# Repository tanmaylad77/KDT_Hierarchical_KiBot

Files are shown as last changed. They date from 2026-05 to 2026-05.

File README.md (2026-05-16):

<p align="center" width="100%">
  
</p>

<h1 align="center">LE_BMS_A_V2</h1>

<p align="center" width="100%">
  <a href="https://github.com/nguyen-v/KDT_Hierarchical_KiBot/actions/workflows/ci.yaml">
    
  </a>
</p>

<p align="center" width="100%">
    
</p>

***

<p align="center">
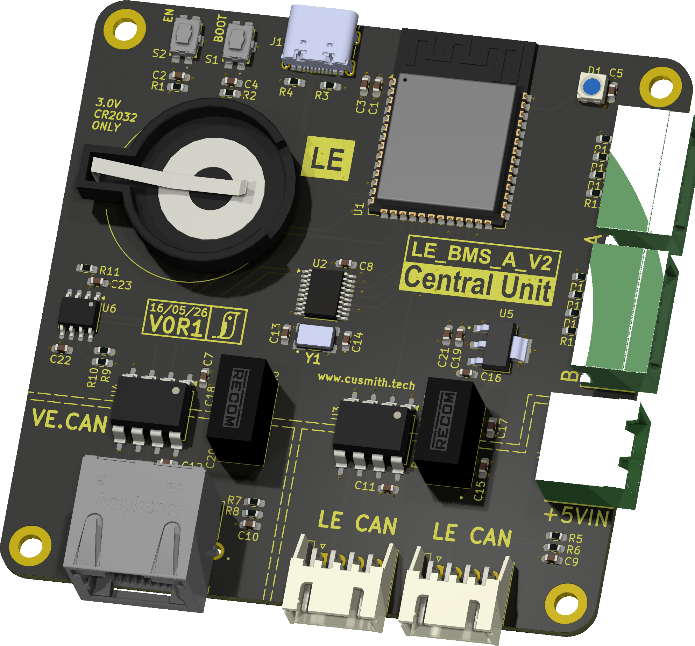
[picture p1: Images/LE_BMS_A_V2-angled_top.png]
3D Top Angled
  
&nbsp; &nbsp; &nbsp; &nbsp;
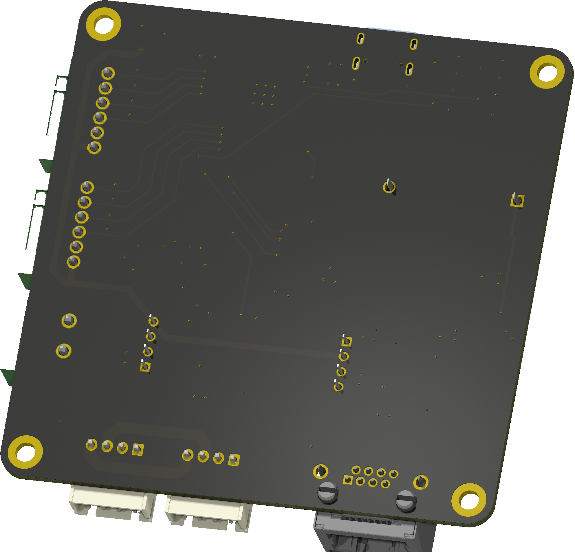
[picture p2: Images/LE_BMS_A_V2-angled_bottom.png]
3D Bottom Angled
  
</p>

***

## SPECIFICATIONS

| Parameter | Value | 
| --- | --- |
| Dimensions | 80.0 × 80.0 mm |

***

## DIRECTORY STRUCTURE

    .
    ├─ Computations       # Misc calculations
    ├─ HTML               # HTML files for generated webpage
    ├─ Images             # Pictures and renders
    │
    ├─ kibot_resources    # External resources for KiBot
    │  ├─ colors          # Color theme for KiCad
    │  ├─ fonts           # Fonts used in the project
    │  ├─ scripts         # External scripts used with KiBot
    │  └─ templates       # Templates for KiBot generated reports
    │
    ├─ kibot_yaml         # KiBot YAML config files
    ├─ KiRI               # KiRI (PCB diff viewer) files
    │
    ├─ lib                # KiCad footprint and symbol libraries
    │  ├─ 3d_models       # Component 3D models
    │  ├─ lib_fp          # Footprint libraries
    │  └─ lib_sym         # Symbol libraries
    │
    ├─ Logos              # Logos
    │
    ├─ Manufacturing      # Assembly and fabrication documents
    │  ├─ Assembly        # Assembly documents (BoM, pos, notes)
    │  │
    │  └─ Fabrication     # Fabrication documents (ZIP, notes)
    │     ├─ Drill Tables # CSV drill tables
    │     └─ Gerbers      # Gerbers
    │
    ├─ Report             # Reports for ERC/DRC
    ├─ Schematic          # PDF of schematic
    ├─ Templates          # Title block templates
    ├─ Testing
    │  └─ Testpoints      # Testpoints tables      
    │
    └─ Variants           # Outputs for assembly variants

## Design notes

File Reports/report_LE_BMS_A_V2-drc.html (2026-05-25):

Logo

(https://github.com/INTI-CMNB/KiBot/) | DRC report for LE_BMS_A_V2
| PCB: LE_BMS_A_V2 Revision: + (Unreleased) Date: 2026-05-25T16:28:53+0000 KiCad Version: 9.0.7 | Errors: 0 Warnings: 95 Total: 95

Violations

Type | Description | Details
silk_edge_clearance | Silkscreen clipped by board edge | @(193.15 mm, 122.61 mm): Segment on Edge.Cuts @(193.15 mm, 95.61 mm): Segment on F.Silkscreen
silk_edge_clearance | Silkscreen clipped by board edge | @(113.15 mm, 50.61 mm): Segment on Edge.Cuts @(179.15 mm, 101.61 mm): Segment on F.Silkscreen
silk_edge_clearance | Silkscreen clipped by board edge | @(193.15 mm, 122.61 mm): Segment on Edge.Cuts @(193.15 mm, 94.61 mm): Segment on F.Silkscreen
silk_edge_clearance | Silkscreen clipped by board edge | @(113.15 mm, 50.61 mm): Segment on Edge.Cuts @(149.15 mm, 102.61 mm): Segment on F.Silkscreen
silk_edge_clearance | Silkscreen clipped by board edge | @(193.15 mm, 122.61 mm): Segment on Edge.Cuts @(183.9 mm, 96.52 mm): Segment of J4 on F.Silkscreen
silk_edge_clearance | Silkscreen clipped by board edge | @(193.15 mm, 122.61 mm): Segment on Edge.Cuts @(196.1 mm, 108.88 mm): Segment of J4 on F.Silkscreen
silk_edge_clearance | Silkscreen clipped by board edge | @(117.15 mm, 126.61 mm): Segment on Edge.Cuts @(168.74 mm, 129.51 mm): Segment of J6 on F.Silkscreen
silk_edge_clearance | Silkscreen clipped by board edge | @(117.15 mm, 126.61 mm): Segment on Edge.Cuts @(171.05 mm, 123.4 mm): Segment of J6 on F.Silkscreen
silk_edge_clearance | Silkscreen clipped by board edge | @(117.15 mm, 126.61 mm): Segment on Edge.Cuts @(171.55 mm, 128.9 mm): Segment of J6 on F.Silkscreen
silk_edge_clearance | Silkscreen clipped by board edge | @(117.15 mm, 126.61 mm): Segment on Edge.Cuts @(173.55 mm, 123.4 mm): Segment of J6 on F.Silkscreen
silk_edge_clearance | Silkscreen clipped by board edge | @(117.15 mm, 126.61 mm): Segment on Edge.Cuts @(174.05 mm, 128.9 mm): Segment of J6 on F.Silkscreen
silk_edge_clearance | Silkscreen clipped by board edge | @(117.15 mm, 126.61 mm): Segment on Edge.Cuts @(176.05 mm, 123.4 mm): Segment of J6 on F.Silkscreen
silk_edge_clearance | Silkscreen clipped by board edge | @(117.15 mm, 126.61 mm): Segment on Edge.Cuts @(176.55 mm, 128.9 mm): Segment of J6 on F.Silkscreen
silk_edge_clearance | Silkscreen clipped by board edge | @(117.15 mm, 126.61 mm): Segment on Edge.Cuts @(178.55 mm, 123.4 mm): Segment of J6 on F.Silkscreen
silk_edge_clearance | Silkscreen clipped by board edge | @(117.15 mm, 126.61 mm): Segment on Edge.Cuts @(179.05 mm, 128.9 mm): Segment of J6 on F.Silkscreen
silk_edge_clearance | Silkscreen clipped by board edge | @(117.15 mm, 126.61 mm): Segment on Edge.Cuts @(181.36 mm, 129.51 mm): Segment of J6 on F.Silkscreen
silk_edge_clearance | Silkscreen clipped by board edge | @(189.15 mm, 46.61 mm): Segment on Edge.Cuts @(139.04 mm, 45.8 mm): Segment of J1 on F.Silkscreen
silk_edge_clearance | Silkscreen clipped by board edge | @(189.15 mm, 46.61 mm): Segment on Edge.Cuts @(147.98 mm, 45.8 mm): Segment of J1 on F.Silkscreen
silk_edge_clearance | Silkscreen clipped by board edge | @(117.15 mm, 126.61 mm): Segment on Edge.Cuts @(125.195 mm, 129.46 mm): Segment of J5 on F.Silkscreen
silk_edge_clearance | Silkscreen clipped by board edge | @(117.15 mm, 126.61 mm): Segment on Edge.Cuts @(141.705 mm, 129.46 mm): Segment of J5 on F.Silkscreen
silk_edge_clearance | Silkscreen clipped by board edge | @(117.15 mm, 126.61 mm): Segment on Edge.Cuts @(153.14 mm, 129.51 mm): Segment of J2 on F.Silkscreen
silk_edge_clearance | Silkscreen clipped by board edge | @(117.15 mm, 126.61 mm): Segment on Edge.Cuts @(155.45 mm, 123.4 mm): Segment of J2 on F.Silkscreen
silk_edge_clearance | Silkscreen clipped by board edge | @(117.15 mm, 126.61 mm): Segment on Edge.Cuts @(155.95 mm, 128.9 mm): Segment of J2 on F.Silkscreen
silk_edge_clearance | Silkscreen clipped by board edge | @(117.15 mm, 126.61 mm): Segment on Edge.Cuts @(157.95 mm, 123.4 mm): Segment of J2 on F.Silkscreen
silk_edge_clearance | Silkscreen clipped by board edge | @(117.15 mm, 126.61 mm): Segment on Edge.Cuts @(158.45 mm, 128.9 mm): Segment of J2 on F.Silkscreen
silk_edge_clearance | Silkscreen clipped by board edge | @(117.15 mm, 126.61 mm): Segment on Edge.Cuts @(160.45 mm, 123.4 mm): Segment of J2 on F.Silkscreen
silk_edge_clearance | Silkscreen clipped by board edge | @(117.15 mm, 126.61 mm): Segment on Edge.Cuts @(160.95 mm, 128.9 mm): Segment of J2 on F.Silkscreen
silk_edge_clearance | Silkscreen clipped by board edge | @(117.15 mm, 126.61 mm): Segment on Edge.Cuts @(162.95 mm, 123.4 mm): Segment of J2 on F.Silkscreen
silk_edge_clearance | Silkscreen clipped by board edge | @(117.15 mm, 126.61 mm): Segment on Edge.Cuts @(163.45 mm, 128.9 mm): Segment of J2 on F.Silkscreen
silk_edge_clearance | Silkscreen clipped by board edge | @(117.15 mm, 126.61 mm): Segment on Edge.Cuts @(165.76 mm, 129.51 mm): Segment of J2 on F.Silkscreen
silk_edge_clearance | Silkscreen clipped by board edge | @(193.15 mm, 122.61 mm): Segment on Edge.Cuts @(185.8 mm, 56.3 mm): Segment of J3 on F.Silkscreen
silk_edge_clearance | Silkscreen clipped by board edge | @(193.15 mm, 122.61 mm): Segment on Edge.Cuts @(196.1 mm, 73.5 mm): Segment of J3 on F.Silkscreen
silk_edge_clearance | Silkscreen clipped by board edge | @(193.15 mm, 122.61 mm): Segment on Edge.Cuts @(185.8 mm, 75.5 mm): Segment of J7 on F.Silkscreen
silk_edge_clearance | Silkscreen clipped by board edge | @(193.15 mm, 122.61 mm): Segment on Edge.Cuts @(196.1 mm, 92.7 mm): Segment of J7 on F.Silkscreen
lib_footprint_mismatch | Footprint 'C_0603_1608Metric_Pad1.08x0.95mm_HandSolder' does not match copy in library 'Capacitor_SMD'. | @(132.575 mm, 56.35 mm): Footprint C4
lib_footprint_mismatch | Footprint 'SOP-8_6.62x9.15mm_P2.54mm' does not match copy in library 'Package_SO'. | @(160.0675 mm, 102.585 mm): Footprint U3
lib_footprint_mismatch | Footprint 'C_0603_1608Metric_Pad1.08x0.95mm_HandSolder' does not match copy in library 'Capacitor_SMD'. | @(150.176802 mm, 54.8 mm): Footprint C3
lib_footprint_mismatch | Footprint 'C_0603_1608Metric_Pad1.08x0.95mm_HandSolder' does not match copy in library 'Capacitor_SMD'. | @(138.75 mm, 99.51 mm): Footprint C18
lib_footprint_mismatch | Footprint 'C_0603_1608Metric_Pad1.08x0.95mm_HandSolder' does not match copy in library 'Capacitor_SMD'. | @(119.7175 mm, 85.625 mm): Footprint C23
lib_footprint_mismatch | Footprint 'R_0603_1608Metric_Pad0.98x0.95mm_HandSolder' does not match copy in library 'Resistor_SMD'. | @(125.525 mm, 57.825 mm): Footprint R1
lib_footprint_mismatch | Footprint 'C_0603_1608Metric_Pad1.08x0.95mm_HandSolder' does not match copy in library 'Capacitor_SMD'. | @(152.0 mm, 79.475 mm): Footprint C8
lib_footprint_mismatch | Footprint 'C_0603_1608Metric_Pad1.08x0.95mm_HandSolder' does not match copy in library 'Capacitor_SMD'. | @(133.25 mm, 109.41 mm): Footprint C12
lib_footprint_mismatch | Footprint 'SOIC-8_3.9x4.9mm_P1.27mm' does not match copy in library 'Package_SO'. | @(118.15 mm, 90.4 mm): Footprint U6
lib_footprint_mismatch | Footprint 'C_0603_1608Metric_Pad1.08x0.95mm_HandSolder' does not match copy in library 'Capacitor_SMD'. | @(153.95 mm, 89.975 mm): Footprint C14
lib_footprint_mismatch | Footprint 'C_0603_1608Metric_Pad1.08x0.95mm_HandSolder' does not match copy in library 'Capacitor_SMD'. | @(166.05 mm, 97.21 mm): Footprint C6
lib_footprint_mismatch | Footprint 'R_0603_1608Metric_Pad0.98x0.95mm_HandSolder' does not match copy in library 'Resistor_SMD'. | @(140.835 mm, 55.383198 mm): Footprint R4
lib_footprint_mismatch | Footprint 'R_0603_1608Metric_Pad0.98x0.95mm_HandSolder' does not match copy in library 'Resistor_SMD'. | @(145.65 mm, 115.01 mm): Footprint R8
lib_footprint_mismatch | Footprint 'C_0603_1608Metric_Pad1.08x0.95mm_HandSolder' does not match copy in library 'Capacitor_SMD'. | @(182.95 mm, 52.0625 mm): Footprint C5
lib_footprint_mismatch | Footprint 'R_0603_1608Metric_Pad0.98x0.95mm_HandSolder' does not match copy in library 'Resistor_SMD'. | @(145.635 mm, 55.383198 mm): Footprint R3
lib_footprint_mismatch | Footprint 'R_0603_1608Metric_Pad0.98x0.95mm_HandSolder' does not match copy in library 'Resistor_SMD'. | @(186.25 mm, 113.61 mm): Footprint R5
lib_footprint_mismatch | Footprint 'R_0603_1608Metric_Pad0.98x0.95mm_HandSolder' does not match copy in library 'Resistor_SMD'. | @(183.4375 mm, 80.35 mm): Footprint R18
lib_footprint_mismatch | Footprint 'JST_XH_S4B-XH-A_1x04_P2.50mm_Horizontal' does not match copy in library 'Connector_JST'. | @(171.3 mm, 120.2 mm): Footprint J6
lib_footprint_mismatch | Footprint 'R_0603_1608Metric_Pad0.98x0.95mm_HandSolder' does not match copy in library 'Resistor_SMD'. | @(117.945 mm, 83.925 mm): Footprint R11
lib_footprint_mismatch | Footprint 'R_0603_1608Metric_Pad0.98x0.95mm_HandSolder' does not match copy in library 'Resistor_SMD'. | @(183.2875 mm, 61.16 mm): Footprint R14
lib_footprint_mismatch | Footprint 'C_0603_1608Metric_Pad1.08x0.95mm_HandSolder' does not match copy in library 'Capacitor_SMD'. | @(145.75 mm, 89.975 mm): Footprint C13
lib_footprint_mismatch | Footprint 'C_0603_1608Metric_Pad1.08x0.95mm_HandSolder' does not match copy in library 'Capacitor_SMD'. | @(168.775 mm, 87.7 mm): Footprint C19
lib_footprint_mismatch | Footprint 'C_0603_1608Metric_Pad1.08x0.95mm_HandSolder' does not match copy in library 'Capacitor_SMD'. | @(175.0375 mm, 105.31 mm): Footprint C15
lib_footprint_mismatch | Footprint 'R_0603_1608Metric_Pad0.98x0.95mm_HandSolder' does not match copy in library 'Resistor_SMD'. | @(183.2875 mm, 66.18 mm): Footprint R12
lib_footprint_mismatch | Footprint 'ESP32-S3-WROOM-2' does not match copy in library 'RF_Module'. | @(162.86 mm, 59.36 mm): Footprint U1
lib_footprint_mismatch | Footprint 'R_0603_1608Metric_Pad0.98x0.95mm_HandSolder' does not match copy in library 'Resistor_SMD'. | @(145.65 mm, 113.41 mm): Footprint R7
lib_footprint_mismatch | Footprint 'SOP-8_6.62x9.15mm_P2.54mm' does not match copy in library 'Package_SO'. | @(130.3 mm, 102.51 mm): Footprint U4
lib_footprint_mismatch | Footprint 'C_0603_1608Metric_Pad1.08x0.95mm_HandSolder' does not match copy in library 'Capacitor_SMD'. | @(175.1 mm, 99.65 mm): Footprint C17
lib_footprint_mismatch | Footprint 'R_0603_1608Metric_Pad0.98x0.95mm_HandSolder' does not match copy in library 'Resistor_SMD'. | @(122.255 mm, 96.525 mm): Footprint R10
lib_footprint_mismatch | Footprint 'R_0603_1608Metric_Pad0.98x0.95mm_HandSolder' does not match copy in library 'Resistor_SMD'. | @(183.2875 mm, 63.67 mm): Footprint R13
lib_footprint_mismatch | Footprint 'R_0603_1608Metric_Pad0.98x0.95mm_HandSolder' does not match copy in library 'Resistor_SMD'. | @(186.25 mm, 115.21 mm): Footprint R6
lib_footprint_mismatch | Footprint 'R_0603_1608Metric_Pad0.98x0.95mm_HandSolder' does not match copy in library 'Resistor_SMD'. | @(132.575 mm, 57.85 mm): Footprint R2
lib_footprint_mismatch | Footprint 'R_0603_1608Metric_Pad0.98x0.95mm_HandSolder' does not match copy in library 'Resistor_SMD'. | @(183.2875 mm, 58.65 mm): Footprint R15
lib_footprint_mismatch | Footprint 'C_0603_1608Metric_Pad1.08x0.95mm_HandSolder' does not match copy in library 'Capacitor_SMD'. | @(162.95 mm, 109.61 mm): Footprint C11
lib_footprint_mismatch | Footprint 'R_0603_1608Metric_Pad0.98x0.95mm_HandSolder' does not match copy in library 'Resistor_SMD'. | @(183.4375 mm, 82.86 mm): Footprint R17
lib_footprint_mismatch | Footprint 'C_0603_1608Metric_Pad1.08x0.95mm_HandSolder' does not match copy in library 'Capacitor_SMD'. | @(145.65 mm, 116.61 mm): Footprint C10
lib_footprint_mismatch | Footprint 'JST_XH_S4B-XH-A_1x04_P2.50mm_Horizontal' does not match copy in library 'Connector_JST'. | @(155.7 mm, 120.2 mm): Footprint J2
lib_footprint_mismatch | Footprint 'C_0603_1608Metric_Pad1.08x0.95mm_HandSolder' does not match copy in library 'Capacitor_SMD'. | @(116.645 mm, 95.325 mm): Footprint C22
lib_footprint_mismatch | Footprint 'C_0603_1608Metric_Pad1.08x0.95mm_HandSolder' does not match copy in library 'Capacitor_SMD'. | @(186.25 mm, 116.81 mm): Footprint C9
lib_footprint_mismatch | Footprint 'C_0603_1608Metric_Pad1.08x0.95mm_HandSolder' does not match copy in library 'Capacitor_SMD'. | @(151.876802 mm, 54.8 mm): Footprint C1
lib_footprint_mismatch | Footprint 'R_0603_1608Metric_Pad0.98x0.95mm_HandSolder' does not match copy in library 'Resistor_SMD'. | @(183.4375 mm, 77.84 mm): Footprint R19
lib_footprint_mismatch | Footprint 'C_0603_1608Metric_Pad1.08x0.95mm_HandSolder' does not match copy in library 'Capacitor_SMD'. | @(138.85 mm, 104.61 mm): Footprint C20
lib_footprint_mismatch | Footprint 'TSSOP-20_4.4x6.5mm_P0.65mm' does not match copy in library 'Package_SO'. | @(149.9875 mm, 84.0 mm): Footprint U2
lib_footprint_mismatch | Footprint 'C_0603_1608Metric_Pad1.08x0.95mm_HandSolder' does not match copy in library 'Capacitor_SMD'. | @(136.05 mm, 97.11 mm): Footprint C7
lib_footprint_mismatch | Footprint 'C_0603_1608Metric_Pad1.08x0.95mm_HandSolder' does not match copy in library 'Capacitor_SMD'. | @(170.575 mm, 92.7 mm): Footprint C16
lib_footprint_mismatch | Footprint 'C_0603_1608Metric_Pad1.08x0.95mm_HandSolder' does not match copy in library 'Capacitor_SMD'. | @(167.075 mm, 87.7 mm): Footprint C21
lib_footprint_mismatch | Footprint 'R_0603_1608Metric_Pad0.98x0.95mm_HandSolder' does not match copy in library 'Resistor_SMD'. | @(183.4375 mm, 85.37 mm): Footprint R16
lib_footprint_mismatch | Footprint 'R_0603_1608Metric_Pad0.98x0.95mm_HandSolder' does not match copy in library 'Resistor_SMD'. | @(122.255 mm, 94.925 mm): Footprint R9
lib_footprint_mismatch | Footprint 'C_0603_1608Metric_Pad1.08x0.95mm_HandSolder' does not match copy in library 'Capacitor_SMD'. | @(125.525 mm, 56.325 mm): Footprint C2
silk_over_copper | Silkscreen clipped by solder mask | @(179.15 mm, 101.61 mm): Segment on F.Silkscreen
solder_mask_bridge | Front solder mask aperture bridges items with different nets | @(146.71 mm, 53.145 mm): Pad A1_B12 [GND] of J1 on L1 (Sig, PWR) @(145.91 mm, 53.145 mm): Pad A4_B9 [unconnected-(J1-VBUS-PadA4_B9)] of J1 on L1 (Sig, PWR)
solder_mask_bridge | Front solder mask aperture bridges items with different nets | @(145.91 mm, 53.145 mm): Pad A4_B9 [unconnected-(J1-VBUS-PadA4_B9)] of J1 on L1 (Sig, PWR) @(145.26 mm, 53.145 mm): Pad B8 [unconnected-(J1-SBU2-PadB8)] of J1 on L1 (Sig, PWR)
solder_mask_bridge | Front solder mask aperture bridges items with different nets | @(144.76 mm, 53.145 mm): Pad A5 [/Project Architecture/Section A - Title A/USB_CC1] of J1 on L1 (Sig, PWR) @(145.26 mm, 53.145 mm): Pad B8 [unconnected-(J1-SBU2-PadB8)] of J1 on L1 (Sig, PWR)
solder_mask_bridge | Front solder mask aperture bridges items with different nets | @(144.76 mm, 53.145 mm): Pad A5 [/Project Architecture/Section A - Title A/USB_CC1] of J1 on L1 (Sig, PWR) @(144.26 mm, 53.145 mm): Pad B7 [/Project Architecture/Section A - Title A/ESP32_USB_D-] of J1 on L1 (Sig, PWR)
solder_mask_bridge | Front solder mask aperture bridges items with different nets | @(143.76 mm, 53.145 mm): Pad A6 [/Project Architecture/Section A - Title A/ESP32_USB_D+] of J1 on L1 (Sig, PWR) @(143.26 mm, 53.145 mm): Pad A7 [/Project Architecture/Section A - Title A/ESP32_USB_D-] of J1 on L1 (Sig, PWR)
solder_mask_bridge | Front solder mask aperture bridges items with different nets | @(143.76 mm, 53.145 mm): Pad A6 [/Project Architecture/Section A - Title A/ESP32_USB_D+] of J1 on L1 (Sig, PWR) @(144.26 mm, 53.145 mm): Pad B7 [/Project Architecture/Section A - Title A/ESP32_USB_D-] of J1 on L1 (Sig, PWR)
solder_mask_bridge | Front solder mask aperture bridges items with different nets | @(143.26 mm, 53.145 mm): Pad A7 [/Project Architecture/Section A - Title A/ESP32_USB_D-] of J1 on L1 (Sig, PWR) @(142.76 mm, 53.145 mm): Pad B6 [/Project Architecture/Section A - Title A/ESP32_USB_D+] of J1 on L1 (Sig, PWR)
solder_mask_bridge | Front solder mask aperture bridges items with different nets | @(142.26 mm, 53.145 mm): Pad A8 [unconnected-(J1-SBU1-PadA8)] of J1 on L1 (Sig, PWR) @(141.76 mm, 53.145 mm): Pad B5 [/Project Architecture/Section A - Title A/USB_CC2] of J1 on L1 (Sig, PWR)
solder_mask_bridge | Front solder mask aperture bridges items with different nets | @(142.26 mm, 53.145 mm): Pad A8 [unconnected-(J1-SBU1-PadA8)] of J1 on L1 (Sig, PWR) @(142.76 mm, 53.145 mm): Pad B6 [/Project Architecture/Section A - Title A/ESP32_USB_D+] of J1 on L1 (Sig, PWR)
solder_mask_bridge | Front solder mask aperture bridges items with different nets | @(140.31 mm, 53.145 mm): Pad B1_A12 [GND] of J1 on L1 (Sig, PWR) @(141.11 mm, 53.145 mm): Pad B4_A9 [unconnected-(J1-VBUS-PadA4_B9)_1] of J1 on L1 (Sig, PWR)
solder_mask_bridge | Front solder mask aperture bridges items with different nets | @(141.11 mm, 53.145 mm): Pad B4_A9 [unconnected-(J1-VBUS-PadA4_B9)_1] of J1 on L1 (Sig, PWR) @(141.76 mm, 53.145 mm): Pad B5 [/Project Architecture/Section A - Title A/USB_CC2] of J1 on L1 (Sig, PWR)

Generated by KiBot (https://github.com/INTI-CMNB/KiBot/) v1.9.1

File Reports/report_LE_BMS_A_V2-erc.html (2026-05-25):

Logo

(https://github.com/INTI-CMNB/KiBot/) | ERC report for LE_BMS_A_V2
| Schematic: LE_BMS_A_V2 Revision: + (Unreleased) Date: 2026-05-25T16:28:51+0000 KiCad Version: 9.0.7 | Errors: 0 Warnings: 6 Total: 6

Sheet / (LE_BMS_A_V2.kicad_sch)

Type | Description | Details
lib_symbol_mismatch | Symbol 'RFM-0505S' doesn't match copy in library 'RFM-0505S' | @(1.1176 mm, 0.6477 mm): Symbol PS1 [RFM-0505S]
lib_symbol_mismatch | Symbol '691313510002' doesn't match copy in library '691313510002' | @(0.9906 mm, 1.1938 mm): Symbol J4 [691313510002]
lib_symbol_mismatch | Symbol 'RFM-0505S' doesn't match copy in library 'RFM-0505S' | @(1.6764 mm, 0.6477 mm): Symbol PS2 [RFM-0505S]
lib_symbol_mismatch | Symbol 'TLV1117LV33DCYT' doesn't match copy in library 'TLV1117LV33DCYT' | @(1.4351 mm, 1.1684 mm): Symbol U5 [TLV1117LV33DCYT]
lib_symbol_mismatch | Symbol 'Battery_Cell' doesn't match copy in library 'Device' | @(1.7399 mm, 0.6096 mm): Symbol BT1 [Battery_Cell]

Sheet /Project Architecture/Section C - POWER/ (untitled.kicad_sch)

Type | Description | Details
pin_to_pin | Pins of type Bidirectional and Power output are connected | @(1.6129 mm, 1.143 mm): Symbol U5 Pin 4 [OUT-1, Bidirectional, Line] @(1.6129 mm, 1.1176 mm): Symbol U5 Pin 2 [OUT, Power output, Line]

Generated by KiBot (https://github.com/INTI-CMNB/KiBot/) v1.9.1

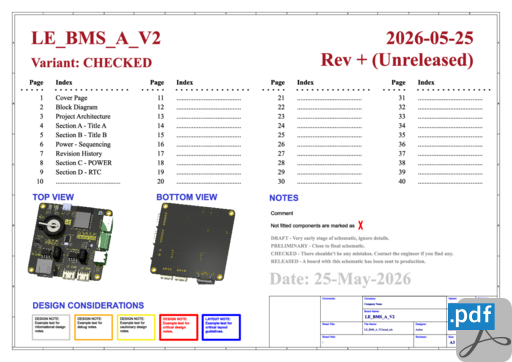
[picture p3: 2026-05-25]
HTML/images/cat_pdf_schematic_LE_BMS_A_V2-schematic.png

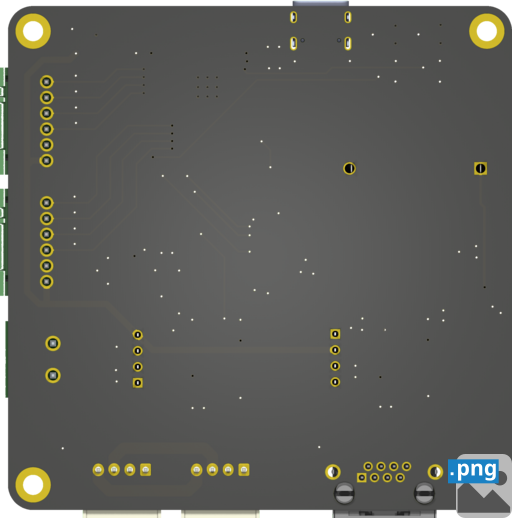
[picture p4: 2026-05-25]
HTML/images/cat_png_3d_viewer_bottom_LE_BMS_A_V2-bottom.png

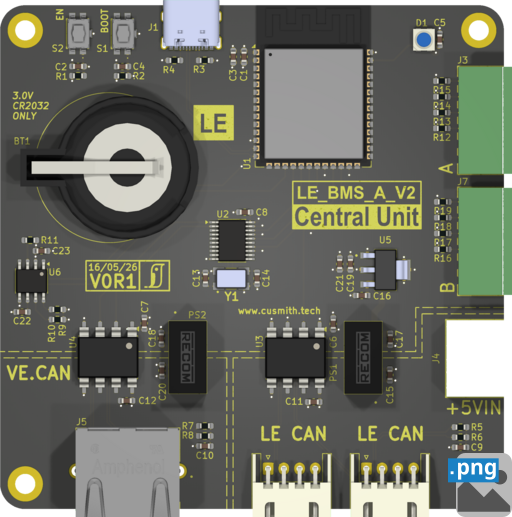
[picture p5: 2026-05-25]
HTML/images/cat_png_3d_viewer_top_LE_BMS_A_V2-top.png

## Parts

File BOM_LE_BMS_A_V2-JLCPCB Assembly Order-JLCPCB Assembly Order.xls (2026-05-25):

JLCPCB BOM Tool - BOM Matching
BOM name：BOM_LE_BMS_A_V2-JLCPCB Assembly Order-JLCPCB Assembly Order.xlsx |  |  | Download Time：2026-05-26 00:19:31 |  |  |  | * Our matching results are updated in real-time, but stock and prices may change. If it's been over 24 hours, please re-match before placing your order.
PCB Assembled Qty：5 |  |  | Est. Total Price：30.7024
Your BOM |  |  |  |  | Matched Parts |  |  |  |  |  |  | Order Information
Top Designator | Bottom Designator | Comment | Footprint | JLCPCB Part # | Matches | Part # | Manufacturer | Footprint | Description | Category | Warning | JLCPCB Part # | Product link | Lib Type | Qty | Source | Total Price ($)
BT1 |  | CR2032 | - |  | Select by System | BS-07-A1BJ001 | MYOUNG | - | -25~85℃ Battery base CR2032 Manganese steel Nickel plated - ROHS | Button And Strip Battery Connector |  | C2979167 | https://jlcpcb.com/partdetail/MYOUNG-BS_07A1BJ001/C2979167 | Extended | 2 | 2 JLCPCB | 0.5516
C1,C3,C5,C6,C7,C8,C11,C12,C15,C16,C17,C18,C19,C20,C21,C22,C23 |  | 1uF | 0603 |  | Select by System | CL10A105KB8NNNC | Samsung Electro-Mechanics | 0603 | 1uF 50V X5R ±10% 0603 Multilayer Ceramic Capacitors MLCC - SMD/SMT ROHS | Multilayer Ceramic Capacitors MLCC - SMD/SMT |  | C15849 | https://jlcpcb.com/partdetail/16531-CL10A105KB8NNNC/C15849 | Basic | 34 | 34 JLCPCB | 0.2584
C2,C4 |  | 0.1uF | 0603 |  | Select by System | CC0603KRX7R9BB104 | YAGEO | 0603 | 100nF 50V X7R ±10% 0603 Multilayer Ceramic Capacitors MLCC - SMD/SMT ROHS | Multilayer Ceramic Capacitors MLCC - SMD/SMT |  | C14663 | https://jlcpcb.com/partdetail/YAGEO-CC0603KRX7R9BB104/C14663 | Basic | 4 | 4 JLCPCB | 0.0128
C9,C10 |  | 4.7n | 0603 |  | Select by System | 0603B472K500NT | FH (Guangdong Fenghua Advanced Tech) | 0603 | 4.7nF 50V X7R ±10% 0603 Multilayer Ceramic Capacitors MLCC - SMD/SMT ROHS | Multilayer Ceramic Capacitors MLCC - SMD/SMT |  | C53987 | https://jlcpcb.com/partdetail/55004-0603B472K500NT/C53987 | Basic | 4 | 4 JLCPCB | 0.014
C13,C14 |  | 10p | 0603 |  | Select by System | CL10C100JB8NNNC | Samsung Electro-Mechanics | 0603 | 10pF 50V C0G ±5% 0603 Multilayer Ceramic Capacitors MLCC - SMD/SMT ROHS | Multilayer Ceramic Capacitors MLCC - SMD/SMT |  | C1634 | https://jlcpcb.com/partdetail/1986-CL10C100JB8NNNC/C1634 | Basic | 4 | 4 JLCPCB | 0.0204
J1 |  | 10155435-00011LF | 插件 |  | Select by System | 10155435-00011LF | Amphenol ICC | 插件 | -25℃~+85℃ 1 3A、5A 5V Female Surface Mount, Right Angle Type-C 插件 USB Connectors ROHS | Global Sourcing Parts |  | C5409177 | https://jlcpcb.com/partdetail/AmphenolICC-1015543500011LF/C5409177 | Extended | 2 | 2 JLCPCB | 1.6232
J2,J6 |  | CAN1 | 弯插,P=2.5mm |  | Select by Customer | S4B-XH-A(LF)(SN) | JST | 弯插,P=2.5mm | -25℃~+85℃ 1 11.5mm 12.4mm 1x4P 2.5mm 250V 3A 4 4P 6.1mm Brass K Pin PA66 Right Angle Tin UL94V-0 White XH 弯插,P=2.5mm Wire To Board Connector ROHS | Wire To Board Connector |  | C157925 | https://jlcpcb.com/partdetail/JST-S4B_XH_A_LF_SN/C157925 | Extended | 5 | 5 JLCPCB | 0.8055
J4 |  | 691313510002 | 插件,P=5.08mm |  | Select by System | 691313510002 | Wurth Elektronik | 插件,P=5.08mm | -40℃~+105℃ 1 1x2P 2 20A 2P 300V 5.08mm Board Side/Socket - Closed Green 插件,P=5.08mm Pluggable System Terminal Block ROHS | Global Sourcing Parts |  | C5362635 | https://jlcpcb.com/partdetail/WurthElektronik-691313510002/C5362635 | Extended | 3 | 3 JLCPCB | 1.6827
J5 |  | RJHSE5380 | 弯插 |  | Select by System | RJHSE5380 | Amphenol ICC | 弯插 | -55℃~+85℃ 1 Gold Non-LED Phosphor bronze RJ45 Jack Right Angle Shielded 弯插 Ethernet Connectors / Modular Connectors (RJ45 RJ11) ROHS | Ethernet Connectors / Modular Connectors (RJ45 RJ11) |  | C464586 | https://jlcpcb.com/partdetail/AmphenolICC-RJHSE5380/C464586 | Extended | 2 | 2 JLCPCB | 1.9928
PS1,PS2 |  | RFM-0505S | SIP,11.5x6mm |  | Select by System | RFM-0505S | YLPTEC | SIP,11.5x6mm | -40℃~+85℃ 1 1.5kV 100kHz 10mm 11.5mm 1W 200mA 2400uF 30mVp-p 5V 5V 6mm 88% Short Circuit Protection、Over-temperature protection、Automatic fault recovery SIP,11.5x6mm Isolated Power Modules ROHS | Isolated Power Modules |  | C22371855 | https://jlcpcb.com/partdetail/YLPTEC-RFM0505S/C22371855 | Extended | 4 | 4 JLCPCB | 7.0772
R1,R2 |  | 100k | 0603 |  | Select by System | 0603WAF1003T5E | UNI-ROYAL(Uniroyal Elec) | 0603 | -55℃~+155℃ 100kΩ 100mW 75V Thick Film Resistor ±1% ±100ppm/℃ 0603 Chip Resistor - Surface Mount ROHS | Chip Resistor - Surface Mount |  | C25803 | https://jlcpcb.com/partdetail/26546-0603WAF1003T5E/C25803 | Basic | 4 | 4 JLCPCB | 0.0072
R3,R4,R9,R10,R11 |  | 5.1k | 0603 |  | Select by System | 0603WAF5101T5E | UNI-ROYAL(Uniroyal Elec) | 0603 | -55℃~+155℃ 100mW 5.1kΩ 75V Thick Film Resistor ±1% ±100ppm/℃ 0603 Chip Resistor - Surface Mount ROHS | Chip Resistor - Surface Mount |  | C23186 | https://jlcpcb.com/partdetail/23913-0603WAF5101T5E/C23186 | Basic | 10 | 10 JLCPCB | 0.016
R5,R6,R7,R8 |  | 50R | 0603 |  | Select by System | RT0603BRE0750RL | YAGEO | 0603 | -55℃~+155℃ 100mW 50Ω 75V Thin Film Resistor ±0.1% ±50ppm/℃ 0603 Chip Resistor - Surface Mount ROHS | Chip Resistor - Surface Mount |  | C849792 | https://jlcpcb.com/partdetail/YAGEO-RT0603BRE0750RL/C849792 | Extended | 20 | 20 JLCPCB | 0.522
R12,R13,R14,R15,R16,R17,R18,R19 |  | 10k | 0603 |  | Select by System | 0603WAF1002T5E | UNI-ROYAL(Uniroyal Elec) | 0603 | -55℃~+155℃ 100mW 10kΩ 75V Thick Film Resistor ±1% ±100ppm/℃ 0603 Chip Resistor - Surface Mount ROHS | Chip Resistor - Surface Mount |  | C25804 | https://jlcpcb.com/partdetail/26547-0603WAF1002T5E/C25804 | Basic | 16 | 16 JLCPCB | 0.0208
S1,S2 |  | EVQ-P2P02W | SMD,4.7x3.5mm |  | Select by System | EVQP2P02W | PANASONIC | SMD,4.7x3.5mm | -40℃~+85℃ 1,000,000 cycles 15V 1N 2.5mm 20mA 3.5mm 4.7mm J-Lead Rectangular Button SPST Surface Mount,Vertical SMD,4.7x3.5mm Tactile Switches ROHS | Tactile Switches |  | C512395 | https://jlcpcb.com/partdetail/PANASONIC-EVQP2P02W/C512395 | Extended | 5 | 5 JLCPCB | 2.025
U2 |  | MCP2515-xST | TSSOP-20 |  | Select by System | MCP2515T-I/ST | Microchip Tech | TSSOP-20 | -40℃~+85℃ 1Mbps 1uA 2.7V~5.5V 5mA CAN Controller SPI TSSOP-20 CAN Controllers ROHS | CAN Controllers |  | C185941 | https://jlcpcb.com/partdetail/MicrochipTech-MCP2515T_IST/C185941 | Extended | 2 | 2 JLCPCB | 2.4106
U3,U4 |  | ISO1050DUB | SOP-8 |  | Select by System | ISO1050DUBR | Texas Instruments | SOP-8 | -55℃~+105℃ 1 1Mbps 2500 3V~5.5V 4.75V~5.25V 50kV/us Bus Fault Detection and Protection、Fail-safe SOP-8 Isolated CAN Transceivers ROHS | Isolated CAN Transceivers |  | C16428 | https://jlcpcb.com/partdetail/TexasInstruments-ISO1050DUBR/C16428 | Extended | 4 | 4 JLCPCB | 2.642
U5 |  | TLV1117LV33DCYT | SOT-223 |  | Select by System | TLV1117LV33DCYR | Texas Instruments | SOT-223 | -40℃~+125℃@(Tj) 1 100uA 1A 3.3V 455mV@(1A) 5.5V 60uVrms 65dB@(1kHz) Fixed Positive Under Voltage Lockout、Over Current Protection、Over Temperature Protection SOT-223 Voltage Regulators - Linear, Low Drop Out (LDO) Regulators ROHS | Voltage Regulators - Linear, Low Drop Out (LDO) Regulators |  | C15578 | https://jlcpcb.com/partdetail/TexasInstruments-TLV1117LV33DCYR/C15578 | Extended | 5 | 5 JLCPCB | 1.1565
U6 |  | DS3231MZ | SOIC-8 |  | Select by System | DS3231MZ+TRL | Analog Devices Inc./Maxim Integrated | SOIC-8 | -40℃~+85℃ 100nA 2.3V~5.5V 200uA Built-in I2C Temperature compensation、Backup power management and battery charging、Alarm function、Periodic interrupt output Yes SOIC-8 Real Time Clocks ROHS | Real Time Clocks |  | C107410 | https://jlcpcb.com/partdetail/108629-DS3231MZTRL/C107410 | Extended | 2 | 2 JLCPCB | 5.9234
Y1 |  | ABM3B-8.000MHZ-10-1-U-T | SMD5032-4P |  | Select by System | ABM3B-8.000MHZ-10-1-U-T | Abracon LLC | SMD5032-4P | -10℃~+60℃ 10pF 200Ω 8MHz ±10ppm ±10ppm SMD5032-4P Crystals ROHS | Crystals |  | C276420 | https://jlcpcb.com/partdetail/AbraconLLC-ABM3B_8_000MHZ_10_1_UT/C276420 | Extended | 2 | 2 JLCPCB | 1.5236
D1 |  | WS2812B-2020 | SMD,2.2x2mm |  | Select by System | WS2812B-2020 | Worldsemi | SMD,2.2x2mm | 0.84mm 200mcd、520mcd、160mcd 2kHz 5V 800Kbit/s Built-in power-on reset circuit、Built-in power-on reset circuit、Integrated intelligent reverse connection protection function R:622.5nm、G:515.6nm、B:470.4nm Top-mount SMD,2.2x2mm RGB LEDs(Built-in IC) ROHS | RGB LEDs(Built-In IC) |  | C965555 | https://jlcpcb.com/partdetail/Worldsemi-WS2812B2020/C965555 | Extended | 5 | 3 JLCPCB | 0.4167
J3,J7 |  | 691382010006 | 插件,P=2.5mm |  | Select by System | 691382010006 | Wurth Elektronik | 插件,P=2.5mm | -40℃~+105℃ 1 1x6P 2.5mm 6 6P Green Through Hole Plugin,P=2.5mm Pluggable System Terminal Block ROHS | Pluggable System Terminal Block |  | C6081006 | https://jlcpcb.com/partdetail/WurthElektronik-691382010006/C6081006 | Extended | 4 | 0 JLCPCB | 0
U1 |  | ESP32-S3-WROOM-2 | SMD |  | Select by System | ESP32-S3-WROOM-2-N32R16V | Espressif Systems | SMD | -103.5dBm -40℃~+65℃ 2.4GHz 20.5dBm 355mA 3V~3.6V 95mA Bluetooth5.0 ESP32-S3R16V On-board PCB Antenna UART、SDIO、SPI、I2C、I2S、USB SMD WiFi Modules ROHS | WiFi Modules |  | C42417293 | https://jlcpcb.com/partdetail/44421476-ESP32_S3_WROOM_2N32R16V/C42417293 | Extended | 2 | 0 JLCPCB | 0

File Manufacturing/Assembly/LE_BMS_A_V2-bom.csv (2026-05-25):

Row | Quantity Per PCB | References | Value | Datasheet | Footprint | Description | Manufacturer | Manufacturer Part Number | Supplier Part Number
1 | 1 | BT1 | CR2032 | ~ | BatteryHolder_MYOUNG_BS-07-A1BJ001_CR2032 | Single-cell battery
2 | 2 | C13 C14 | 10p | ~ | C_0603_1608Metric_Pad1.08x0.95mm_HandSolder | Unpolarized capacitor
3 | 2 | C9 C10 | 4.7n | ~ | C_0603_1608Metric_Pad1.08x0.95mm_HandSolder | Unpolarized capacitor
4 | 2 | C2 C4 | 0.1uF | ~ | C_0603_1608Metric_Pad1.08x0.95mm_HandSolder | Unpolarized capacitor
5 | 17 | C1 C3 C5 C6 C7 C8 C11 C12 C15 C16 C17 C18 C19 C20 C21 C22 C23 | 1uF | ~ | C_0603_1608Metric_Pad1.08x0.95mm_HandSolder | Unpolarized capacitor
6 | 1 | D1 | WS2812B-2020 | https://cdn-shop.adafruit.com/product-files/4684/4684_WS2812B-2020_V1.3_EN.pdf | LED_WS2812B-2020_PLCC4_2.0x2.0mm | RGB LED with integrated controller, 2.0 x 2.0 mm, 12 mA
7 | 1 | J1 | 10155435-00011LF |  | AMPHENOL_10155435-00011LF |  | Amphenol
8 | 1 | J4 | 691313510002 |  | 691313510002
9 | 2 | J3 J7 | 691382010006 |  | 691382010006
10 | 2 | J2 J6 | CAN1 | ~ | JST_XH_S4B-XH-A_1x04_P2.50mm_Horizontal | Generic connector, single row, 01x04, script generated
11 | 1 | J5 | RJHSE5380 |  | AMPHENOL_RJHSE5380 |  | Amphenol
12 | 2 | PS1 PS2 | RFM-0505S |  | CONV_RFM-0505S |  | Recom
13 | 4 | R5 R6 R7 R8 | 50R | ~ | R_0603_1608Metric_Pad0.98x0.95mm_HandSolder | Resistor
14 | 5 | R3 R4 R9 R10 R11 | 5.1k | ~ | R_0603_1608Metric_Pad0.98x0.95mm_HandSolder | Resistor
15 | 8 | R12 R13 R14 R15 R16 R17 R18 R19 | 10k | ~ | R_0603_1608Metric_Pad0.98x0.95mm_HandSolder | Resistor
16 | 2 | R1 R2 | 100k | ~ | R_0603_1608Metric_Pad0.98x0.95mm_HandSolder | Resistor
17 | 2 | S1 S2 | EVQ-P2P02W | https://www.digikey.com/en/products/detail/panasonic-electronic-components/EVQ-P2P02W/593455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 | EVQP2P02W | Tactile Switches 4.7x3.5mm SMD Light Touch Switch
18 | 1 | U6 | DS3231MZ | http://datasheets.maximintegrated.com/en/ds/DS3231M.pdf | SOIC-8_3.9x4.9mm_P1.27mm | ±5ppm, I2C Real-Time Clock SOIC-8
19 | 1 | U1 | ESP32-S3-WROOM-2 | https://www.espressif.com/sites/default/files/documentation/esp32-s3-wroom-2_datasheet_en.pdf | ESP32-S3-WROOM-2 | RF Module, 2.4 GHz, Wi-Fi, Bluetooth, BLE, ESP32--S3R8V
20 | 2 | U3 U4 | ISO1050DUB | http://www.ti.com/lit/ds/symlink/iso1050.pdf | SOP-8_6.62x9.15mm_P2.54mm | Isolated CAN Transceiver, SOP-8
21 | 1 | U2 | MCP2515-xST | http://ww1.microchip.com/downloads/en/DeviceDoc/21801e.pdf | TSSOP-20_4.4x6.5mm_P0.65mm | Stand-Alone CAN Controller with SPI Interface, TSSOP-20
22 | 1 | U5 | TLV1117LV33DCYT |  | SOT230P700X180-4N
23 | 1 | Y1 | ABM3B-8.000MHZ-10-1-U-T | https://abracon.com/Resonators/abm3b.pdf | ABM3B | 8 MHz +/-10ppm Crystal 10pF 200 Ohms 4-SMD, No Lead

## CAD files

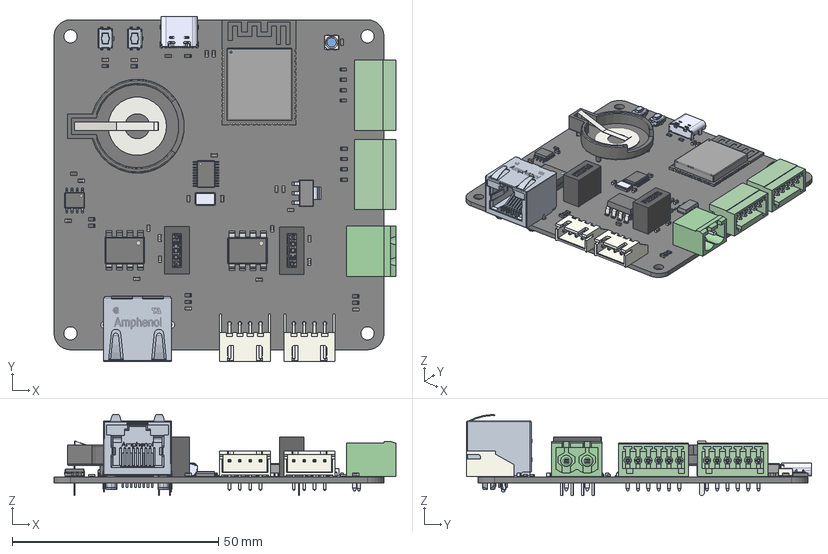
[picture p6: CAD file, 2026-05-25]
3D/LE_BMS_A_V2.step
82.9 x 83.6 x 19.6 mm
C_0603_1608Metric x 23
SOP-8_6.605x9.655mm_P2.54mm x 2
TLV1117LV33DCYT
R_0603_1608Metric x 19
SOIC-8_3.9x4.9mm_P1.27mm
6913135100xx_PIN x 2
JST_XH_S4B-XH-A_1x04_P2.50mm_Horizontal x 2
ABM3B-8.000MHZ-10-1-U-T
RFM_potting x 2
RFM_pin1(-Vin) x 2
RFM_pin2(+Vin) x 2
RFM_pin3(-Vout) x 2
RFM_case x 2
RFM_pin4(+Vout) x 2
ESP32-S3-WROOM-2
BatteryHolder_Keystone_103_1x20mm
EVQ-P2P02W x 2
10155435-00011LF
RJHSE5380
6913820100xx_PIN x 12
LED_WS2812B-Mini_PLCC4_3.5x3.5mm
TSSOP-20_4.4x6.5mm_P0.65mm
kibot_rm7o43i6_PCB

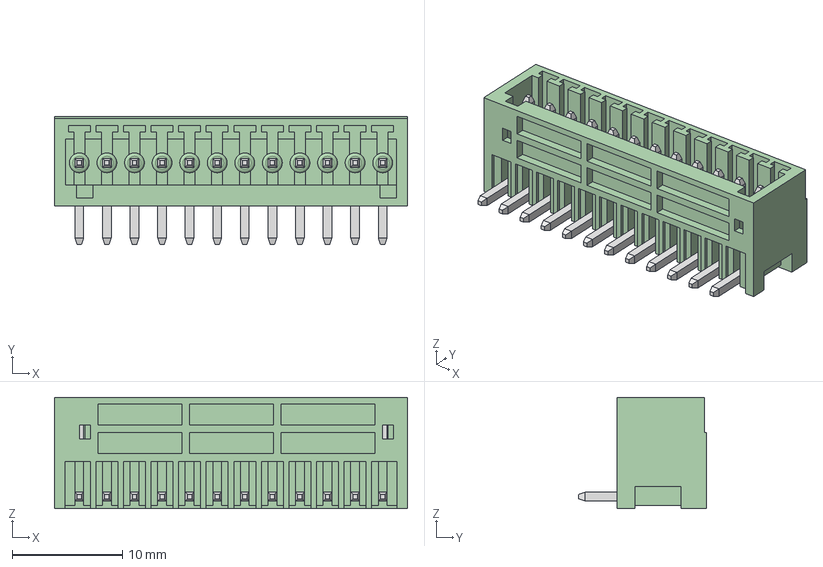
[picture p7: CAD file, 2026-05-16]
parts/691382010012/w12.stp
32.0 x 11.6 x 10.1 mm
6913820100xx_PIN x 12

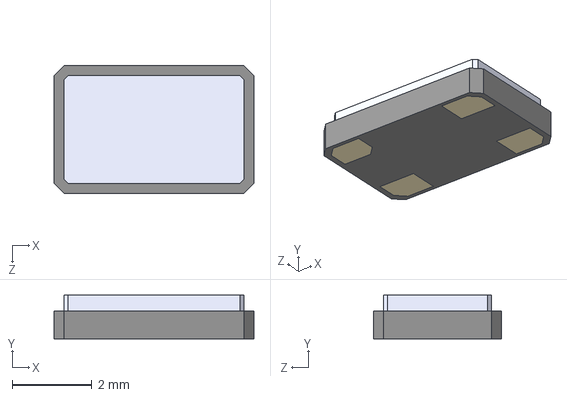
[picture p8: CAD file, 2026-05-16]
parts/ABM3B-8.000MHZ-10-1-U-T/ABM3B-8.000MHZ-10-1-U-T.stp
5.00 x 1.10 x 3.20 mm

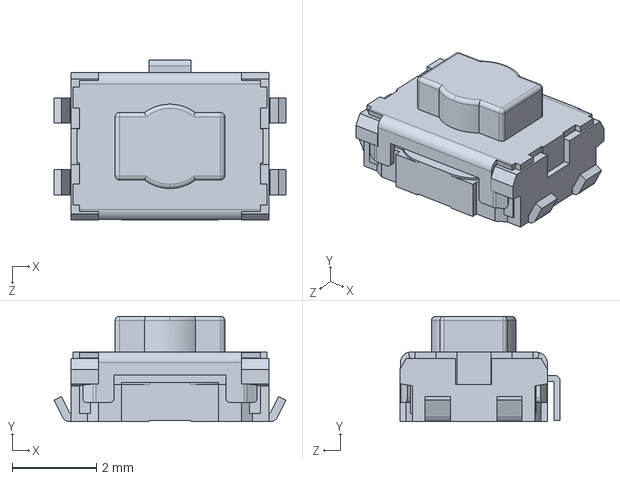
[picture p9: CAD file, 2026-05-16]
parts/EVQ-P2P02W/EVQ-P2P02W.stp
5.50 x 2.50 x 3.80 mm

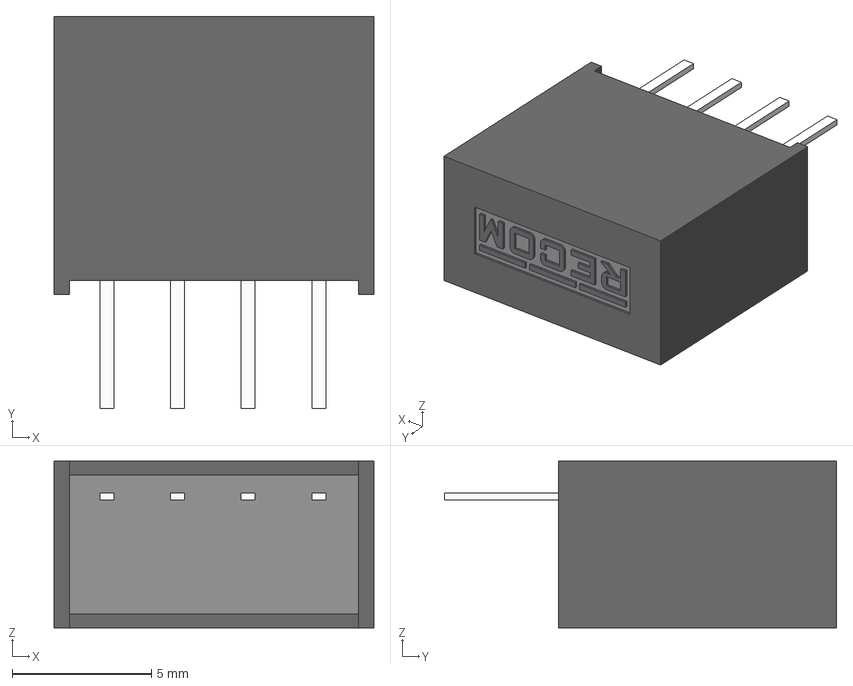
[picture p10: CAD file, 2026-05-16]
parts/RFM-0505S/RFM-0505S.step
11.5 x 14.1 x 6.00 mm

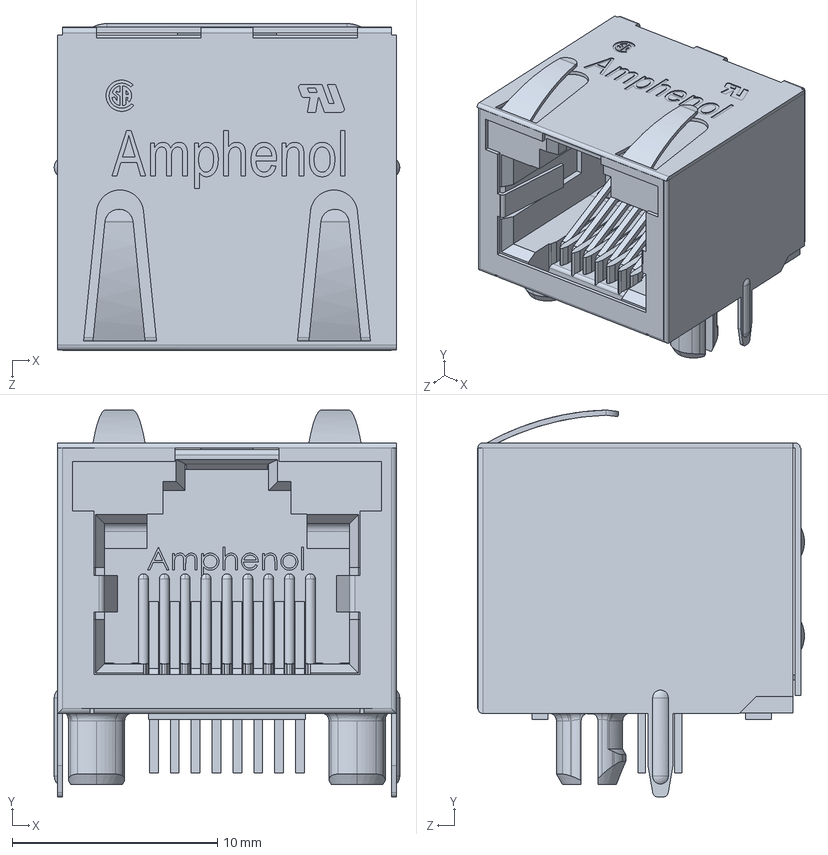
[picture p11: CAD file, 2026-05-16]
parts/RJHSE5380/RJHSE5380.step
16.8 x 18.8 x 15.9 mm

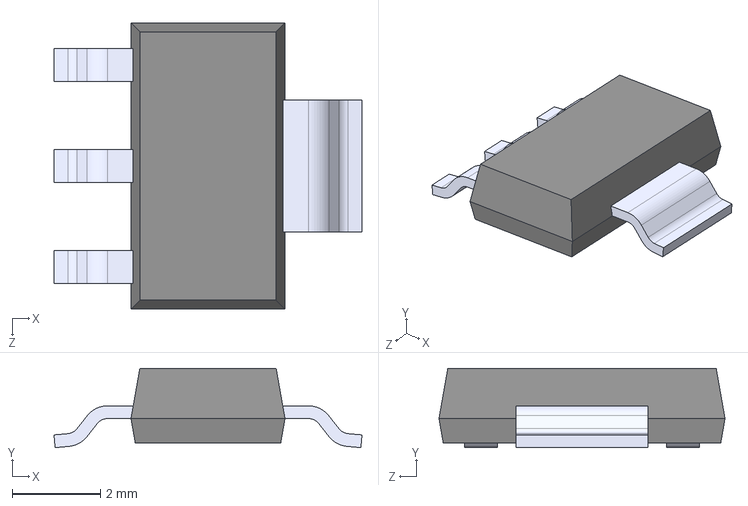
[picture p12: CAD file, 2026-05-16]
parts/TLV1117LV33DCYT/TLV1117LV33DCYT.step
7.00 x 1.80 x 6.50 mm

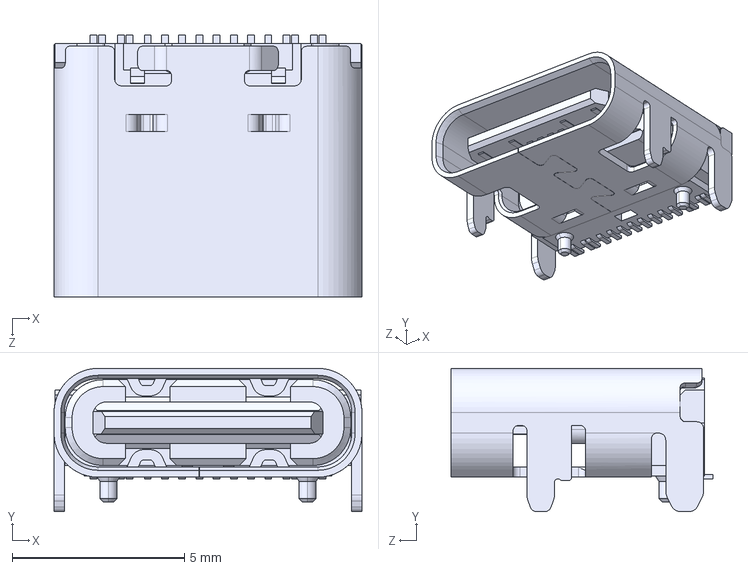
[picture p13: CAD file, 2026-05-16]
parts/10155435-00011LF/10155435-00011LF.step
8.94 x 4.16 x 7.60 mm

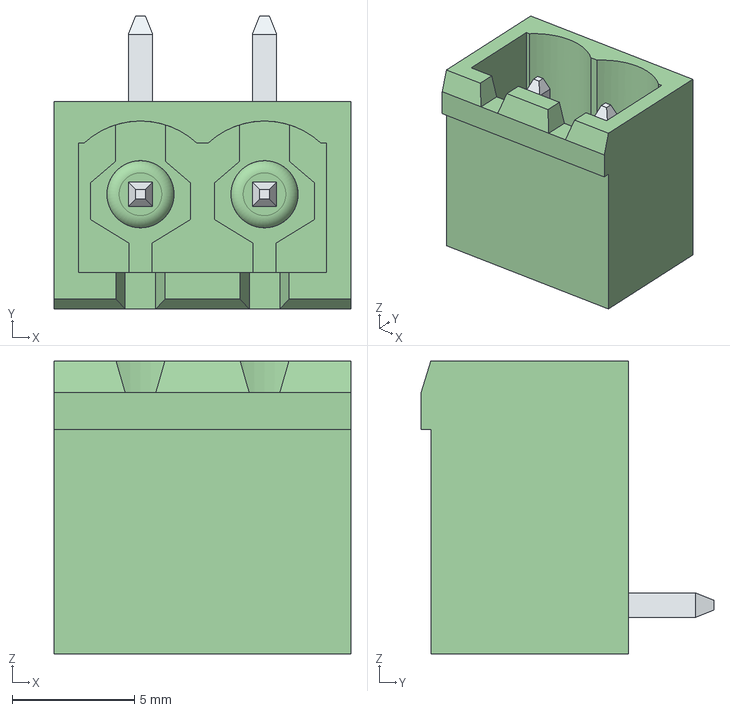
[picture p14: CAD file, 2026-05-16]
parts/691313510002/691313510002.step
12.2 x 12.0 x 12.0 mm
6913135100xx_PIN x 2

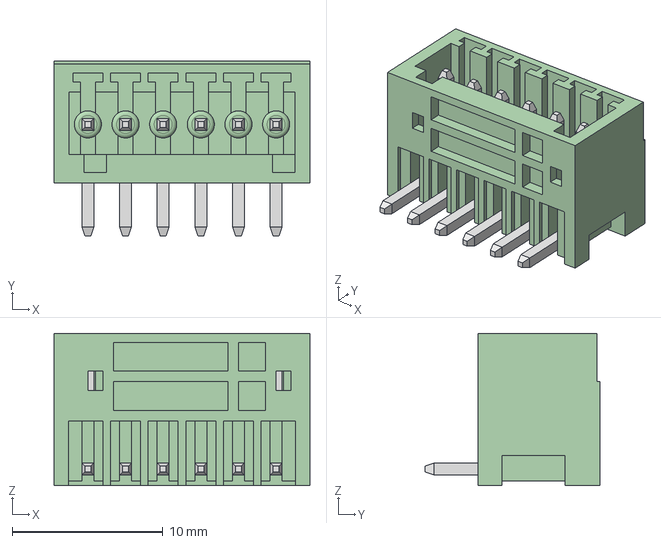
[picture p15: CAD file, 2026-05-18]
parts/691382010006/691382010006.step
17.0 x 11.6 x 10.1 mm
6913820100xx_PIN x 6

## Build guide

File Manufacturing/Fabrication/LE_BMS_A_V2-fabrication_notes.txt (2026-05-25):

FABRICATION NOTES (UNLESS OTHERWISE SPECIFIED)

1)	FABRICATE PER IPC-6012A CLASS 2.

2)	OUTLINE DEFINED IN SEPARATE GERBER FILE WITH
	"Edge_Cuts.GBR" SUFFIX.

	DIMENSIONS OF CIRCUMSIZED RECTANGLE SHOWN ON THIS
	DRAWING FOR REFERENCE ONLY.

3)	SEE SEPARATE DRILL FILES WITH ".DRL" SUFFIX 
	FOR HOLE LOCATIONS.

	SELECTED HOLE LOCATIONS SHOWN ON THIS DRAWING 
	FOR REFERENCE ONLY.

4)	SURFACE FINISH: IMMERSION GOLD

5)	SOLDERMASK ON BOTH SIDES OF THE BOARD SHALL 
	BE LPI, COLOR BLACK.

6)	SILK SCREEN LEGEND TO BE APPLIED PER LAYER 
	STACKUP USING YELLOW NON-CONDUCTIVE EPOXY INK.

7)	ALL VIAS ARE TENTED ON BOTH SIDES UNLESS 
	SOLDERMASK OPENED IN GERBER.

8)	VENDOR SHOULD FOLLOW ROHS COMPLIANT PROCESS 
	AND Pb FREE FOR MANUFACTURING

9)	PCB MATERIAL REQUIREMENTS:

	A.	FLAMMABILITY RATING MUST MEET OR EXCEED 
		UL94V-0 REQUIREMENTS.
	B.	Tg 170 C OR EQUIVALENT.
	C.	EQUIVALENT MATERIAL SHALL BE RoHS COMPLIANT, 
		HALOGEN FREE AND APPROVED BY COMPANY NAME.

10)	DESIGN GEOMETRY MINIMUM FEATURE SIZES:

	BOARD SIZE				80.000 × 80.000 mm
	BOARD THICKNESS		1.660 mm
	TRACE WIDTH			0.200 mm
	TRACE TO TRACE		0.200 mm
	MIN. HOLE (PTH)			0.300 mm
	MIN. HOLE (NPTH)		0.650 mm
	ANNULAR RING			0.150 mm
	COPPER TO HOLE		0.150 mm
	COPPER TO EDGE		0.250 mm
	HOLE TO HOLE			0.254 mm

11)	REFER TO IMPEDANCE TABLE FOR IMPEDANCE CONTROL REQUIREMENTS.

12)	CONFIRM SPACE WIDTHS AND SPACINGS.

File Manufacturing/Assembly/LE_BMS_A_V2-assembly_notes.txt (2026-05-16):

ASSEMBLY NOTES (UNLESS OTHERWISE SPECIFIED)

1)	DO NOT POPULATE PARTS ARE MARKED WITH A RED CROSS.

2)	DO NOT POPULATE PARTS ARE NOT PRESENT IN THE BOM.

3)	IF CONFLICTING INFORMATION IS FOUND BETWEEN THE ASSEMBLY
	FILE AND BOM, BOM SHOULD BE USED AS THE MAIN SOURCE.

4)	CONFORMAL COATING IS NOT REQUIRED.

5)	DOT IDENTIFIES PIN #1 LOCATION AND DEVICE ORIENTATION
	WHEN VIEWED FROM THE TOP.

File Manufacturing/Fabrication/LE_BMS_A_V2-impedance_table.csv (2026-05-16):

Transmission Line | Impedance [ohms] | Tolerance [ohms] | Layer | Trace Width [mm] | Gap [mm] | Ref. Layers
Edge-Coupled Coated Microstrip | 100 | ±10 % | L1 | 0.2032 | 0.28 | L2

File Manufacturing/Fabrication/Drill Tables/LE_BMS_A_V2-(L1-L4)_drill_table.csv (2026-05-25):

Count | Hole Size | Plated | Hole Shape | Drill Layer Pair | Hole Type
113 | 0.30mm (11.81mils) | PTH | Round | L1 (Sig, PWR) - L6 (Sig, PWR) | Via
4 | 0.65mm (25.59mils) | PTH | Slot | L1 (Sig, PWR) - L6 (Sig, PWR) | Pad
8 | 0.94mm (37.01mils) | PTH | Round | L1 (Sig, PWR) - L6 (Sig, PWR) | Pad
8 | 0.95mm (37.40mils) | PTH | Round | L1 (Sig, PWR) - L6 (Sig, PWR) | Pad
8 | 1.00mm (39.37mils) | PTH | Round | L1 (Sig, PWR) - L6 (Sig, PWR) | Pad
12 | 1.40mm (55.12mils) | PTH | Round | L1 (Sig, PWR) - L6 (Sig, PWR) | Pad
2 | 1.50mm (59.06mils) | PTH | Round | L1 (Sig, PWR) - L6 (Sig, PWR) | Pad
2 | 1.60mm (62.99mils) | PTH | Round | L1 (Sig, PWR) - L6 (Sig, PWR) | Pad
2 | 1.62mm (63.78mils) | PTH | Round | L1 (Sig, PWR) - L6 (Sig, PWR) | Pad
4 | 3.20mm (125.98mils) | PTH | Round | L1 (Sig, PWR) - L6 (Sig, PWR) | Pad
Total 163

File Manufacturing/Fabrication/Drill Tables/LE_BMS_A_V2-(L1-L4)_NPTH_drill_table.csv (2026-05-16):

Count | Hole Size | Plated | Hole Shape | Drill Layer Pair | Hole Type
2 | 0.65mm (25.59mils) | NPTH | Round | L1 (Sig, PWR) - L6 (Sig, PWR) | Mechanical
2 | 3.30mm (129.92mils) | NPTH | Round | L1 (Sig, PWR) - L6 (Sig, PWR) | Mechanical
Total 4

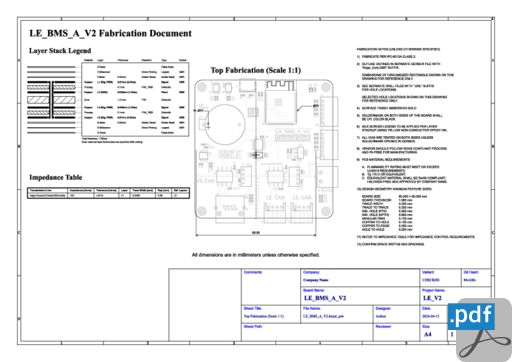
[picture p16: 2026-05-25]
HTML/images/cat_pdf_fabrication_LE_BMS_A_V2-fabrication.png

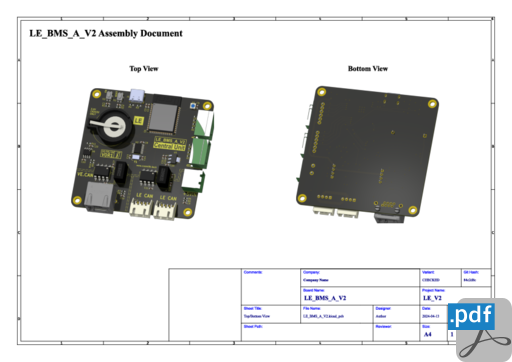
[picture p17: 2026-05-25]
HTML/images/cat_pdf_assembly_LE_BMS_A_V2-assembly.png

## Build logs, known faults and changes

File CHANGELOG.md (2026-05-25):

# Changelog

## [Unreleased]

## [0.1.0] - 2026-05-25

### Fixed

-   Fixes

### Added

-   Additions

### Changed

-   Changes

### Removed

-   Deletions

[Unreleased]: https://github.com/tanmaylad77/KDT_Hierarchical_KiBot/compare/0.1.0...HEAD

[0.1.0]: https://github.com/tanmaylad77/KDT_Hierarchical_KiBot/compare/59e726742e63c5d25a89d796df81468cfdf1e532...0.1.0

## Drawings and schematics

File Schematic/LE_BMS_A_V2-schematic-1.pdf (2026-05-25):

2026-05-25

# Variant:CHECKED

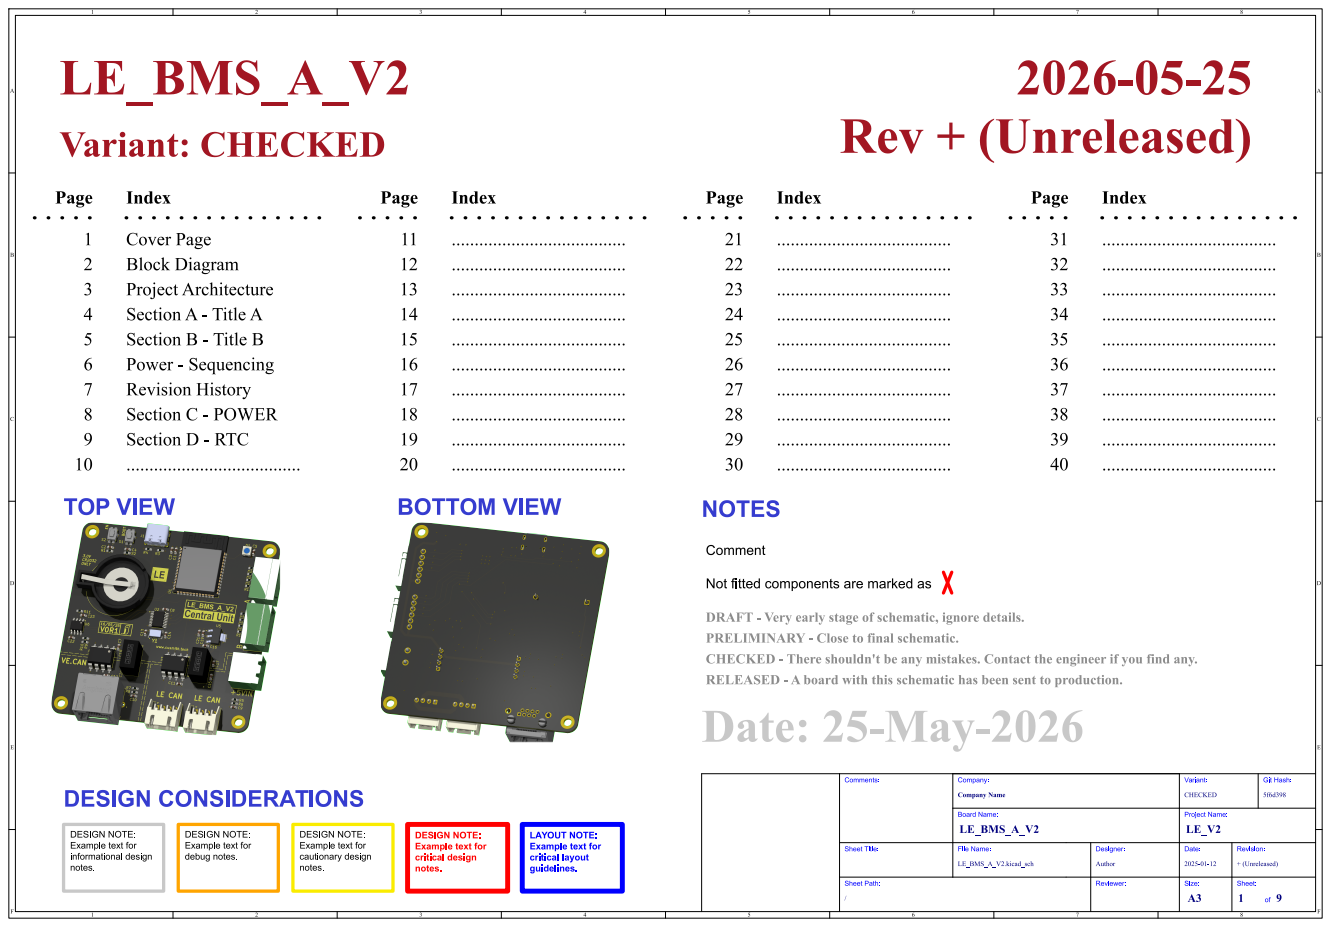
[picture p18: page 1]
Sheet: of 9; Size: A3; LE_BMS_A_V2.kicad_sch; Author Board Name:; Variant: CHECKED; Company:; CompanyName LE_BMS_A_V2; Sheet Title:; File Name:; /Sheet Path: Comments:; Git Hash: 5f6d398 ProjectArchitecture; kibot_image_png_3d_viewer_angled_top; LAYOUT NOTE:; kibot_image_png_3d_viewer_angled_bottom; Rev+ (Unreleased); Page; Index; BOTTOM VIEW; DESIGN CONSIDERATIONS; TOP VIEW; SectionA - Title A; ...................................... ProjectArchitecture; Power- Sequencing; SectionB - Title B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

Not fitted components are marked as

DRAFT - Veryearlystageof schematic,ignoredetails.
PRELIMINARY - Closetofinal schematic.
CHECKED - Thereshouldn'tbeanymistakes.Contacttheengineerif youfindany.
RELEASED - A boardwiththisschematichasbeensenttoproduction.

Revision: + (Unreleased) Date: Project Name: 2025-01-12 Reviewer: Designer:

DESIGN NOTE:
Example text for
informational design
notes.

debug notes.

cautionary design

critical design

critical layout
guidelines.

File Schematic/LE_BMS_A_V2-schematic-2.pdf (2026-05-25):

## Page4

# [2] BlockDiagram

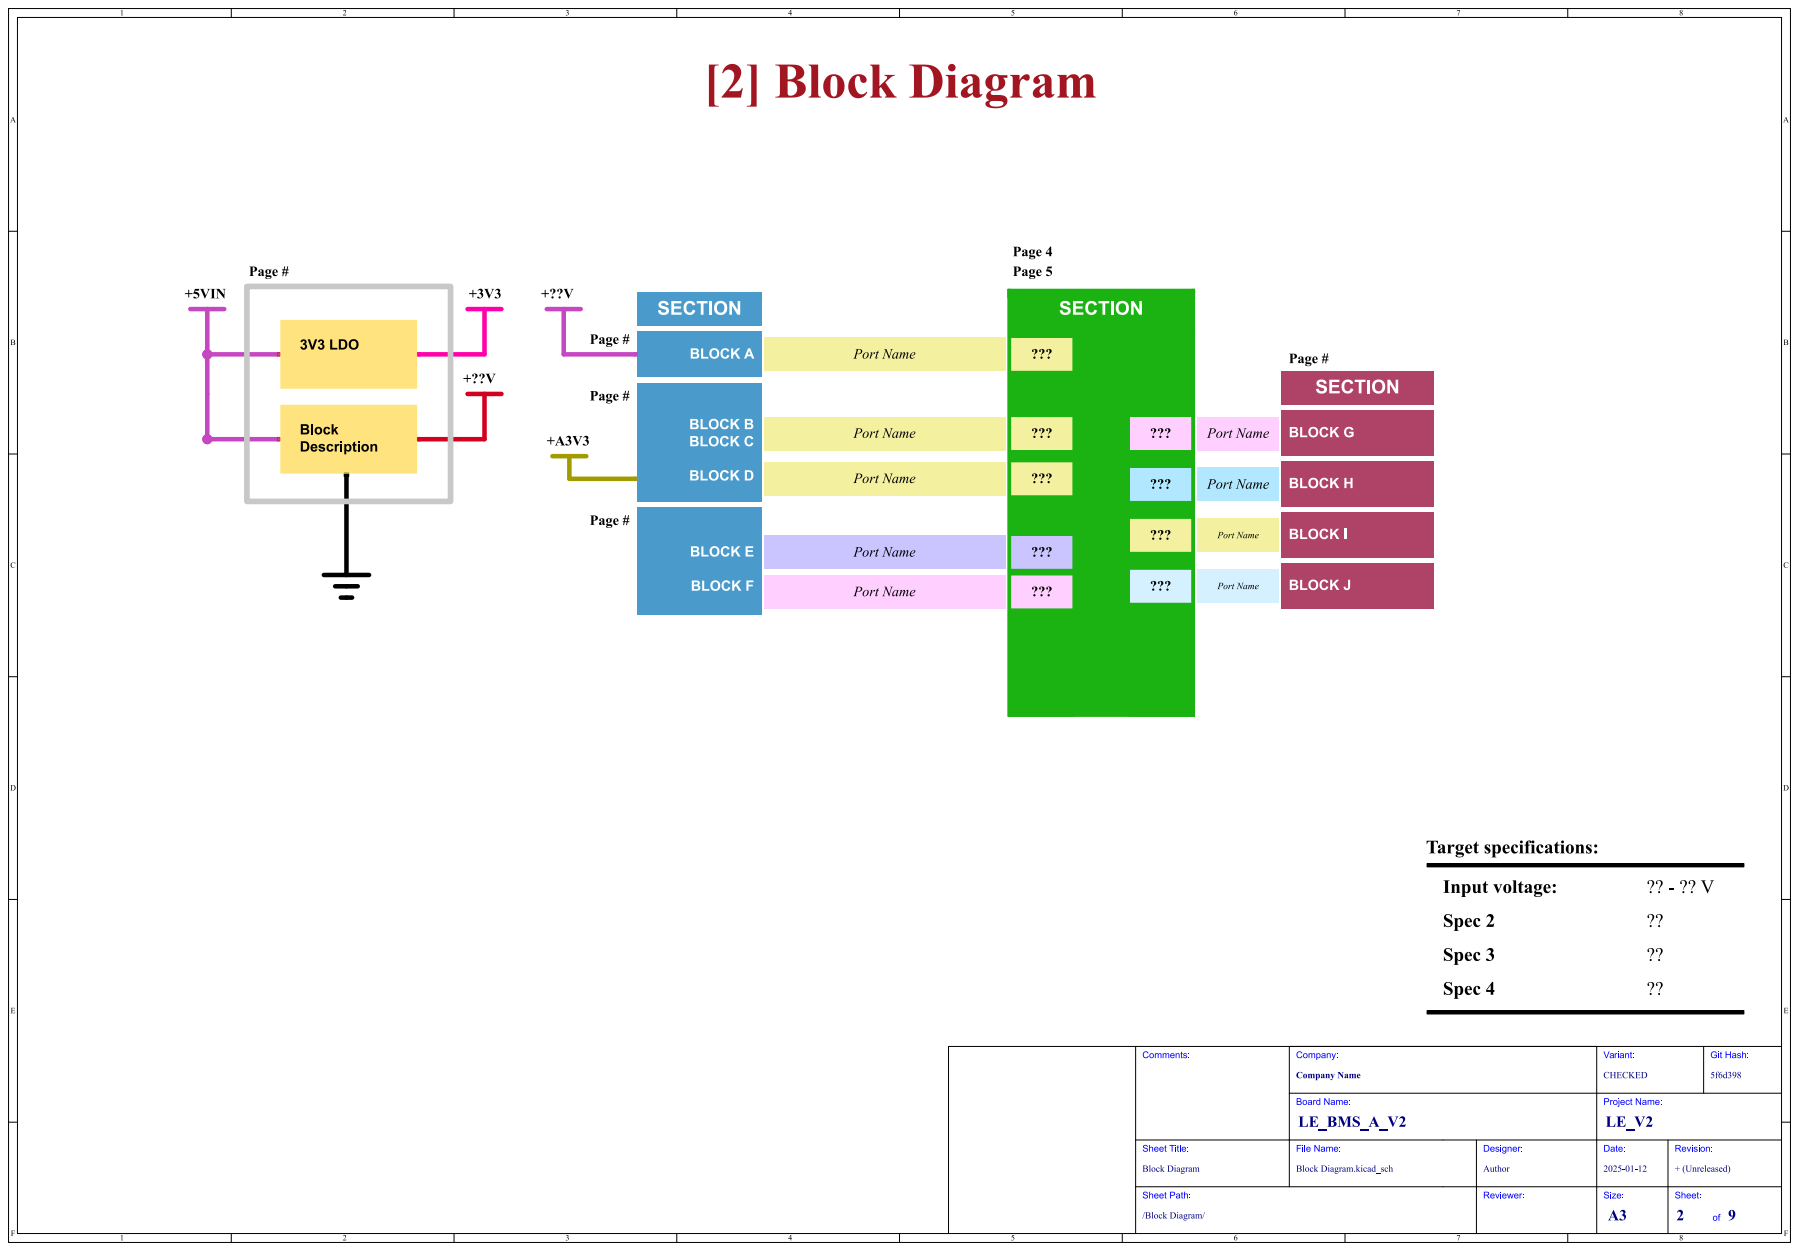
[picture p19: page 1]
Sheet: of 9; Size: A3; Revision: + (Unreleased) Date: Project Name: 2025-01-12 Reviewer: Designer: Block Diagram.kicad_sch; Author Board Name:; Variant: CHECKED; Company:; CompanyName LE_BMS_A_V2; Sheet Title:; File Name:; Comments:; Git Hash: 5f6d398; Page#; Input voltage:; BLOCK J; BLOCK I; BLOCK H; SECTION; BLOCK G; Spec3 Spec4; Spec2; Port Name; Page5; Port Name ???; Targetspecifications:; 3V3 LDO; Block Description; BLOCK B BLOCK C; BLOCK D; BLOCK E; BLOCK F; BLOCK A; +5VIN

Port Name

/Block Diagram/ Sheet Path: Block Diagram

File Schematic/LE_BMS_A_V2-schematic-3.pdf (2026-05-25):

# [3] ProjectArchitecture

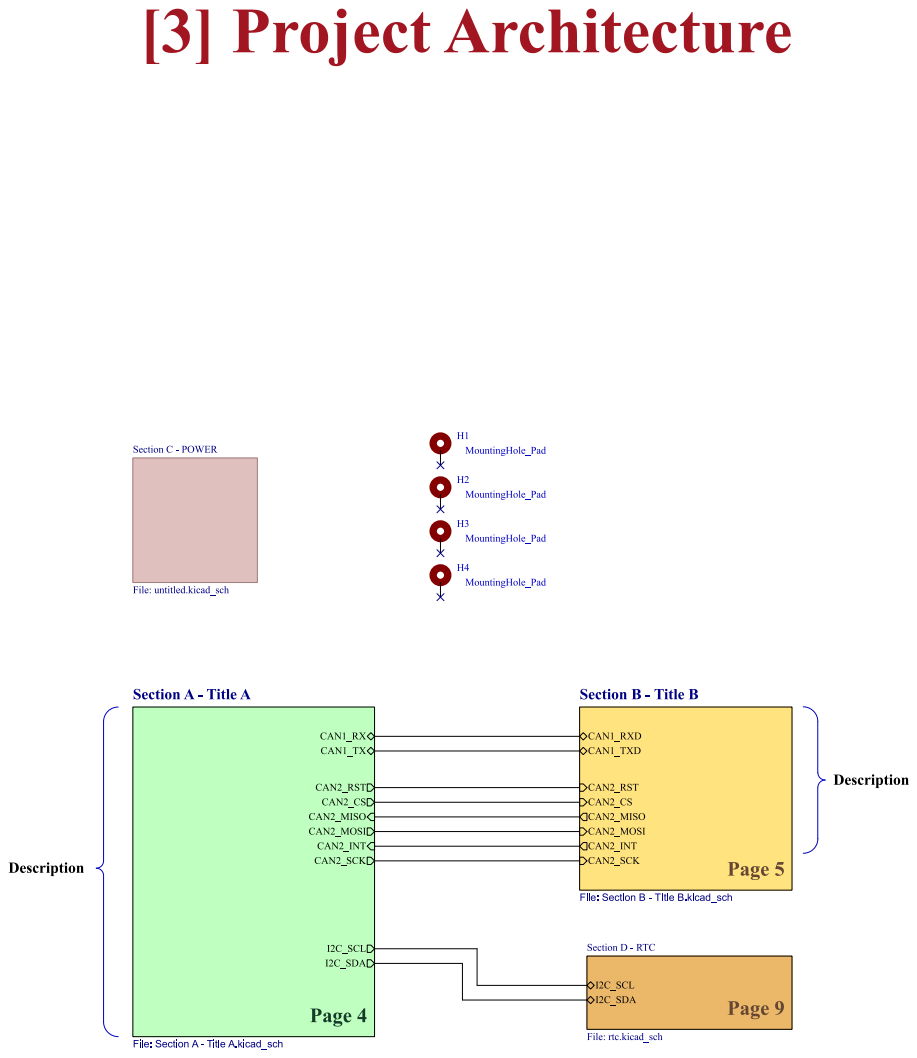
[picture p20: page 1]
Sheet: of 9; Size: A3; ProjectArchitecture.kicad_sch; Author Board Name:; Variant: CHECKED; Company:; CompanyName LE_BMS_A_V2; Sheet Title:; File Name:; /ProjectArchitecture/ Sheet Path: ProjectArchitecture Comments:; Git Hash: 5f6d398; SectionC - POWER; File: untitled.kicad_sch; I2C_SCL I2C_SDA; SectionD - RTC; File: rtc.kicad_sch CAN1_RXD CAN1_TXD; CAN2_CS CAN2_INT CAN2_MISO; CAN2_MOSI CAN2_RST CAN2_SCK SectionB - Title B; CAN2_MOSI CAN2_RST CAN2_SCK; I2C_SCL; I2C_SDA SectionA - Title A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

File: Section B - TItle B.kicad_sch CAN1_RX CAN1_TX CAN2_CS CAN2_INT CAN2_MISO

File: Section A - Title A.kicad_sch

Revision: + (Unreleased) Date: Project Name: 2025-01-12 Reviewer: Designer:

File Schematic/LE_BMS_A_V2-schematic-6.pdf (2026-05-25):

# 3 PS2 RFM-0505S 5V and5V_CAN2 Generation

# [8] Power

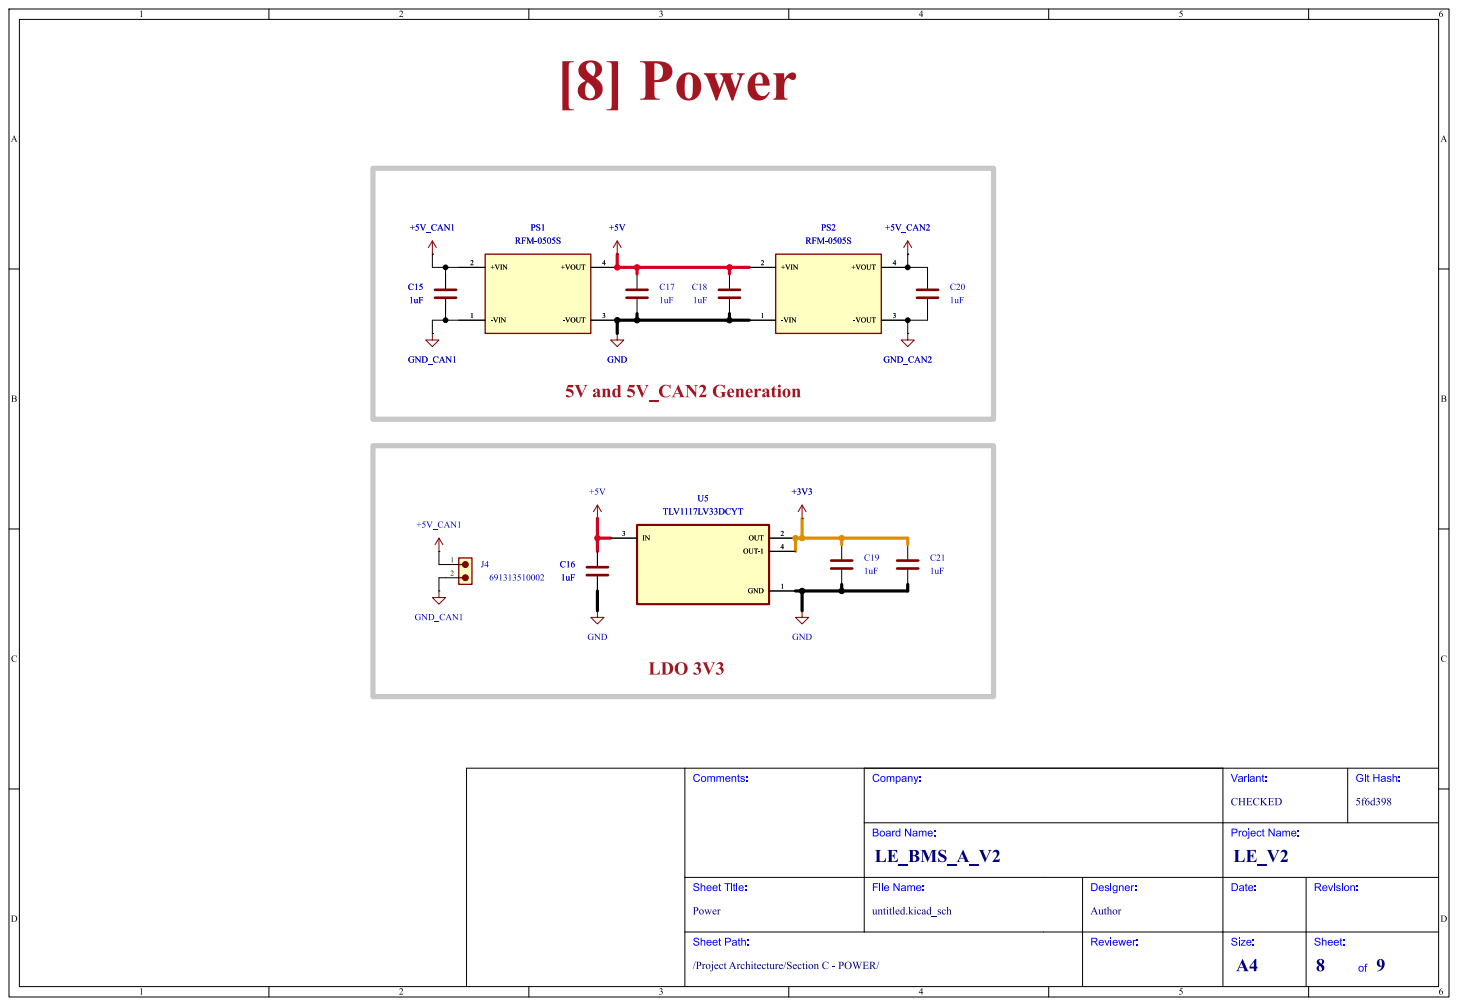
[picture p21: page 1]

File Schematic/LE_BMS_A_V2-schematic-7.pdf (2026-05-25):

# [9] RTC

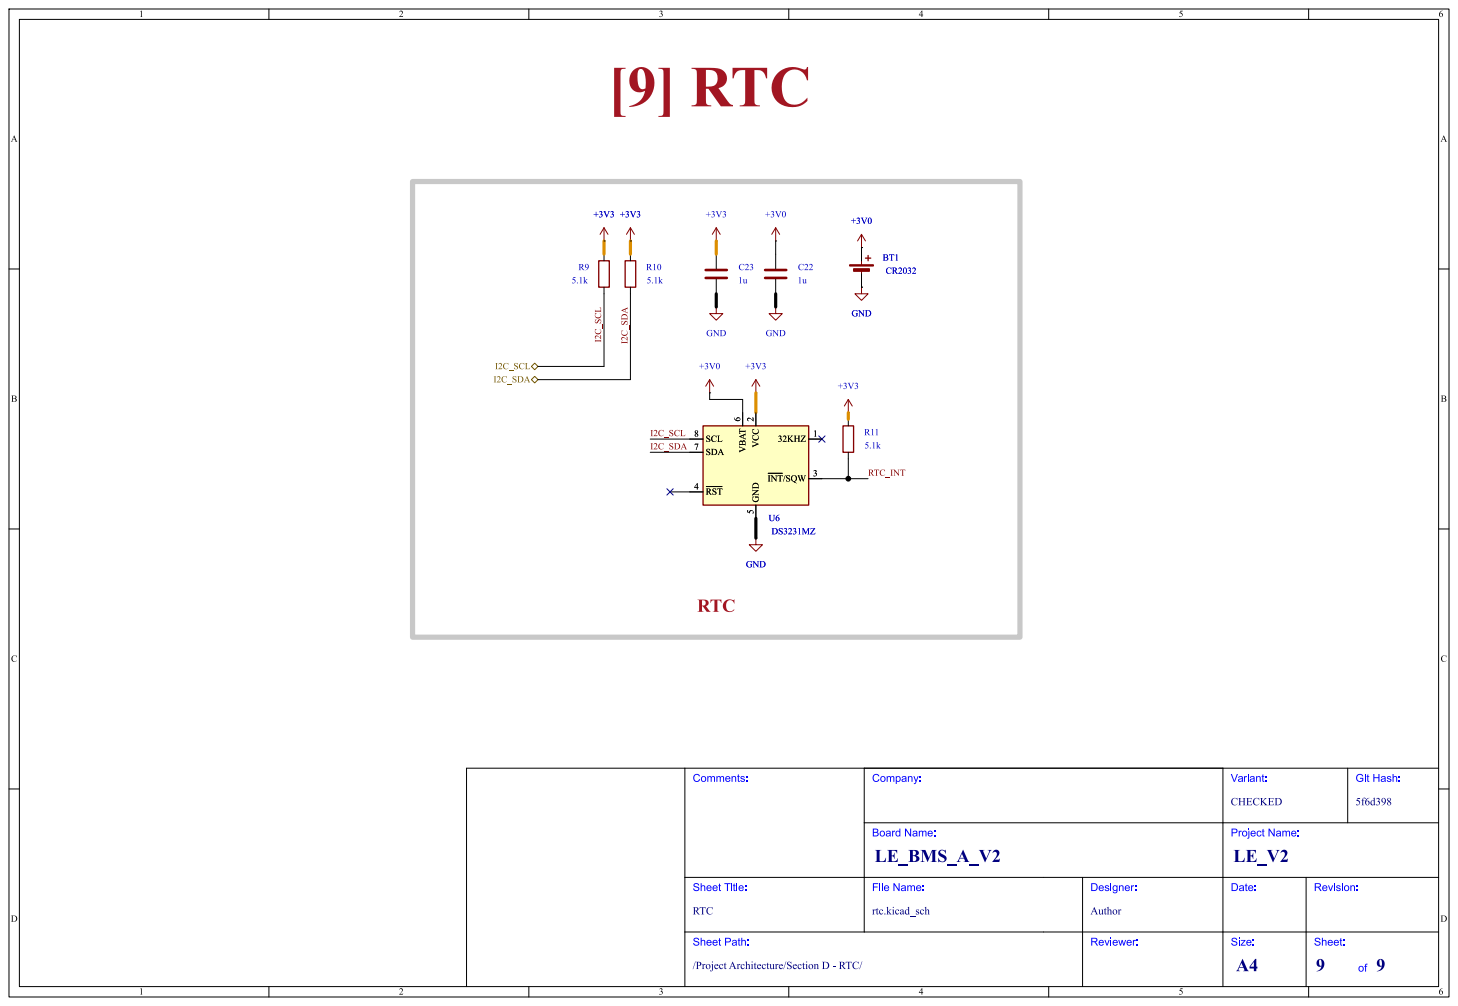
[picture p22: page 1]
Sheet: of 9; Size: A4; Date:; Revision: Project Name: Reviewer: Designer:; rtc.kicad_sch; Author Board Name:; Variant: CHECKED; Company:; LE_BMS_A_V2; Sheet Title:; File Name:; Comments:; Git Hash: 5f6d398 GND; 5.1k SCL 8 SDA 7 ~{RST} 4; VBAT; 6 VCC; 2 GND; 32KHZ 1 ~{INT}/SQW3 U6DS3231MZ GND; 1u +3V0 GND; GND; I2C_SDA; I2C_SCL; RTC_INT; I2C_SCL I2C_SCL; RTC; U6DS3231MZ SCL 8 SDA 7 ~{RST} 4; 32KHZ 1 ~{INT}/SQW3 GND; BT1 CR2032 GND

/ProjectArchitecture/SectionD - RTC/ Sheet Path: RTC

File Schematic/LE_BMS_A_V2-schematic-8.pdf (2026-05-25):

## SOURCE LEVEL

# [6] Power- Sequencing

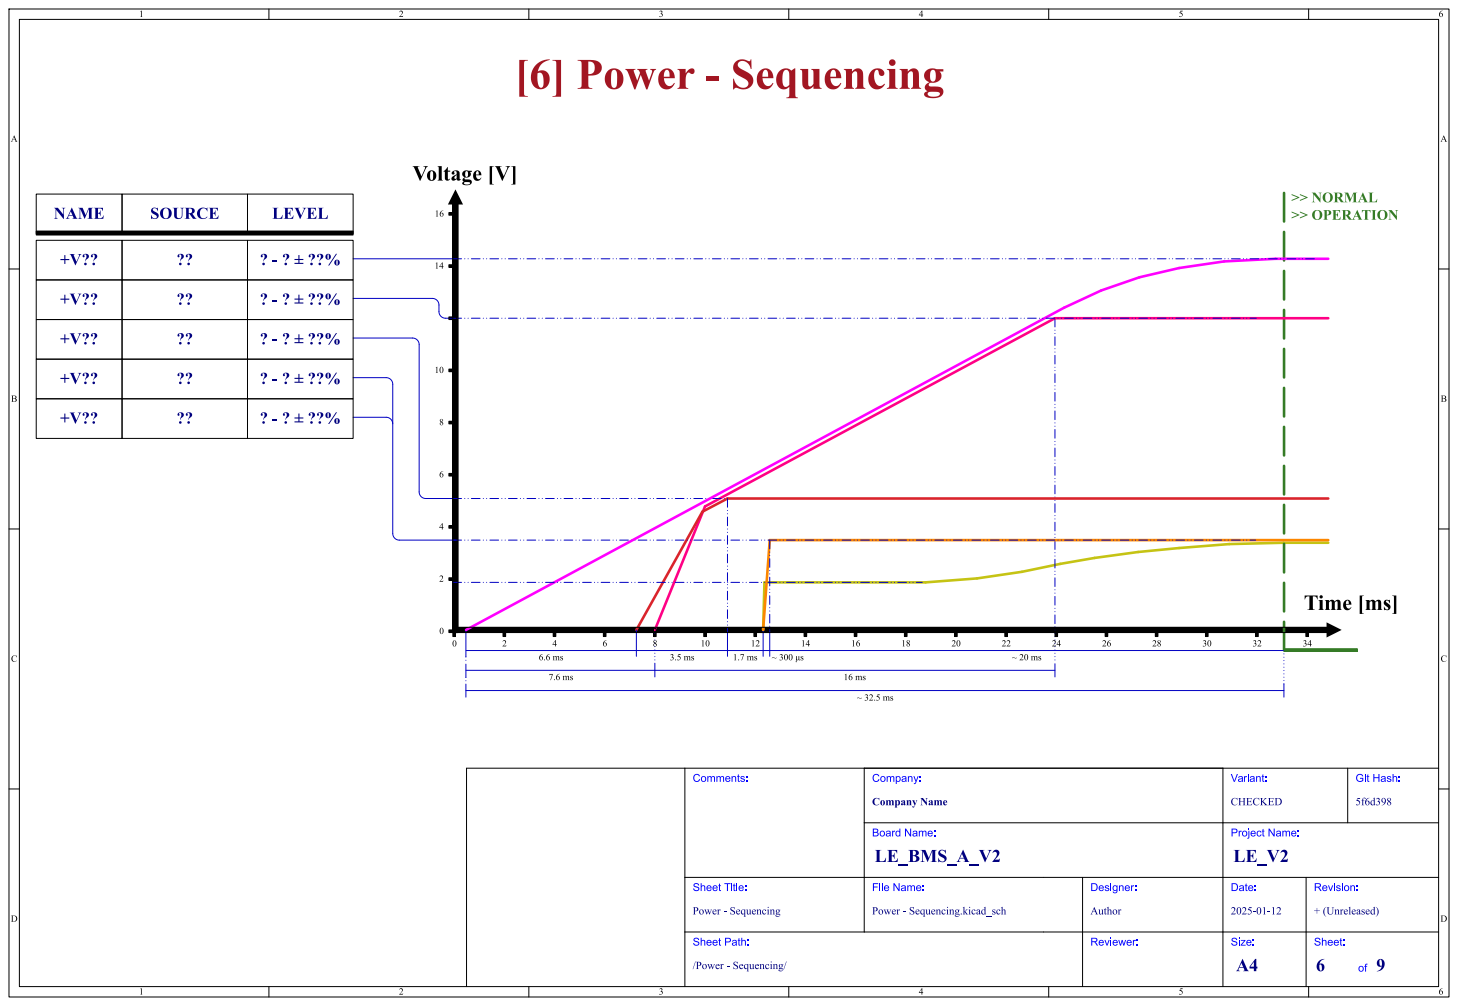
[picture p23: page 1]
Sheet: of 9; Size: A4; Revision: + (Unreleased) Date: Project Name: 2025-01-12 Reviewer: Designer: Power- Sequencing.kicad_sch; Author Board Name:; Variant: CHECKED; Company:; CompanyName LE_BMS_A_V2; Sheet Title:; File Name:; /Power- Sequencing/ Sheet Path: Power- Sequencing Comments:; Git Hash: 5f6d398; NAME; >> NORMAL; >> OPERATION; Voltage[V]; Time[ms]

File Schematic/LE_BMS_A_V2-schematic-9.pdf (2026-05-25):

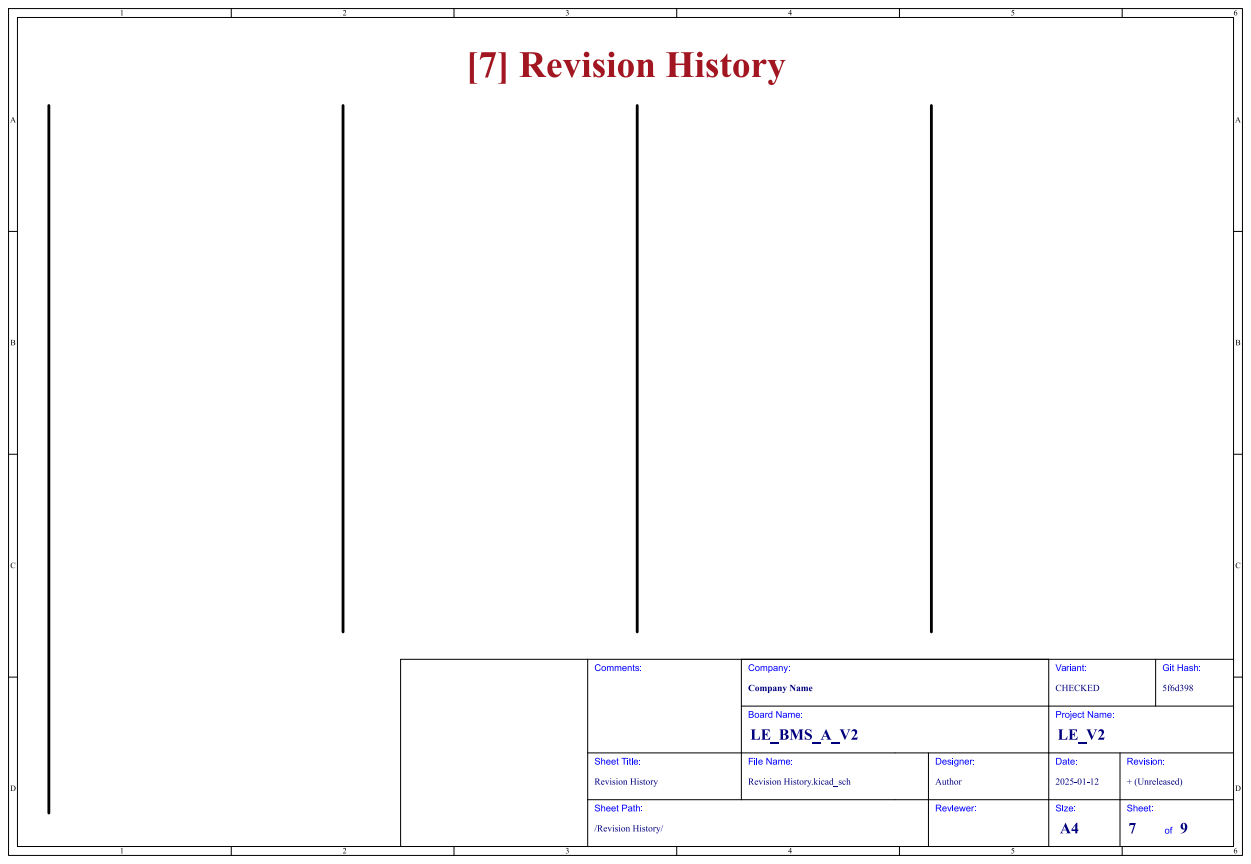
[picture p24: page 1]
Sheet: of 9; Size: A4; Revision: + (Unreleased) Date: Project Name: 2025-01-12 Reviewer: Designer: RevisionHistory.kicad_sch; Author Board Name:; Variant: CHECKED; Company:; CompanyName LE_BMS_A_V2; Sheet Title:; File Name:; /RevisionHistory/ Sheet Path: RevisionHistory Comments:; Git Hash: 5f6d398 [7] RevisionHistory

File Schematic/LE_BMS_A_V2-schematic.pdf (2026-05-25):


Not fitted components are marked as

DRAFT - Veryearlystageof schematic,ignoredetails.
PRELIMINARY - Closetofinal schematic.
CHECKED - Thereshouldn'tbeanymistakes.Contacttheengineerif youfindany.
RELEASED - A boardwiththisschematichasbeensenttoproduction.

Revision: + (Unreleased) Date: Project Name: 2025-01-12 Reviewer: Designer:


Port Name | ??? | Port Name

BLOCK G

Port Name

/Block Diagram/ Sheet Path: Block Diagram


Revision: + (Unreleased) Date: Project Name: 2025-01-12 Reviewer: Designer:

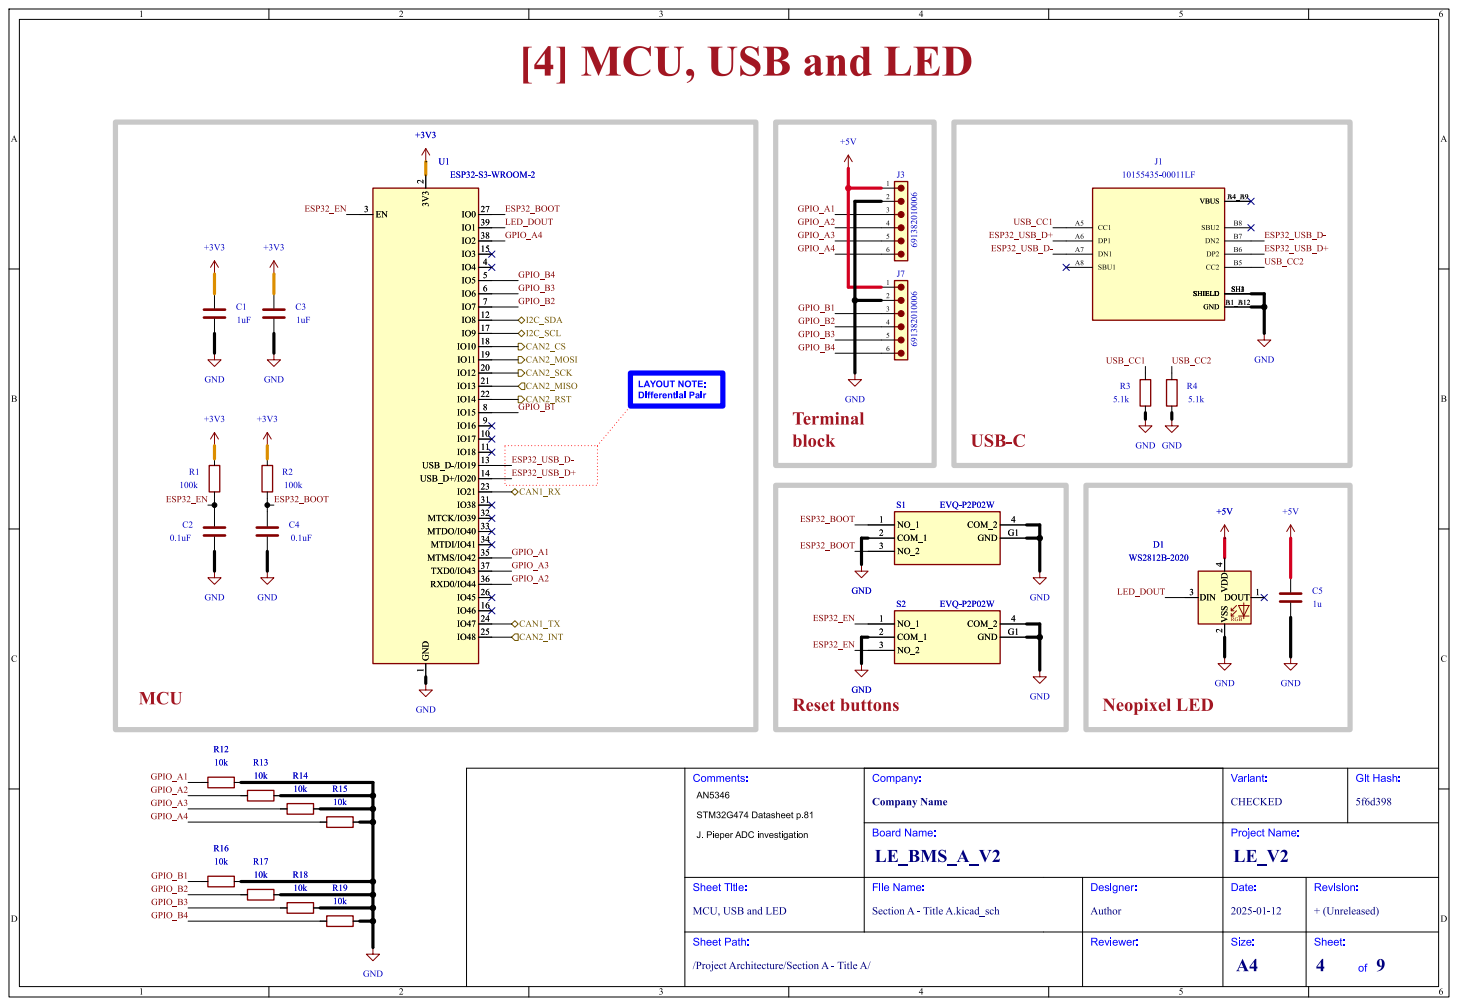
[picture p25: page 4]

/ProjectArchitecture/SectionA - Title A/ Sheet Path: MCU, USBandLED

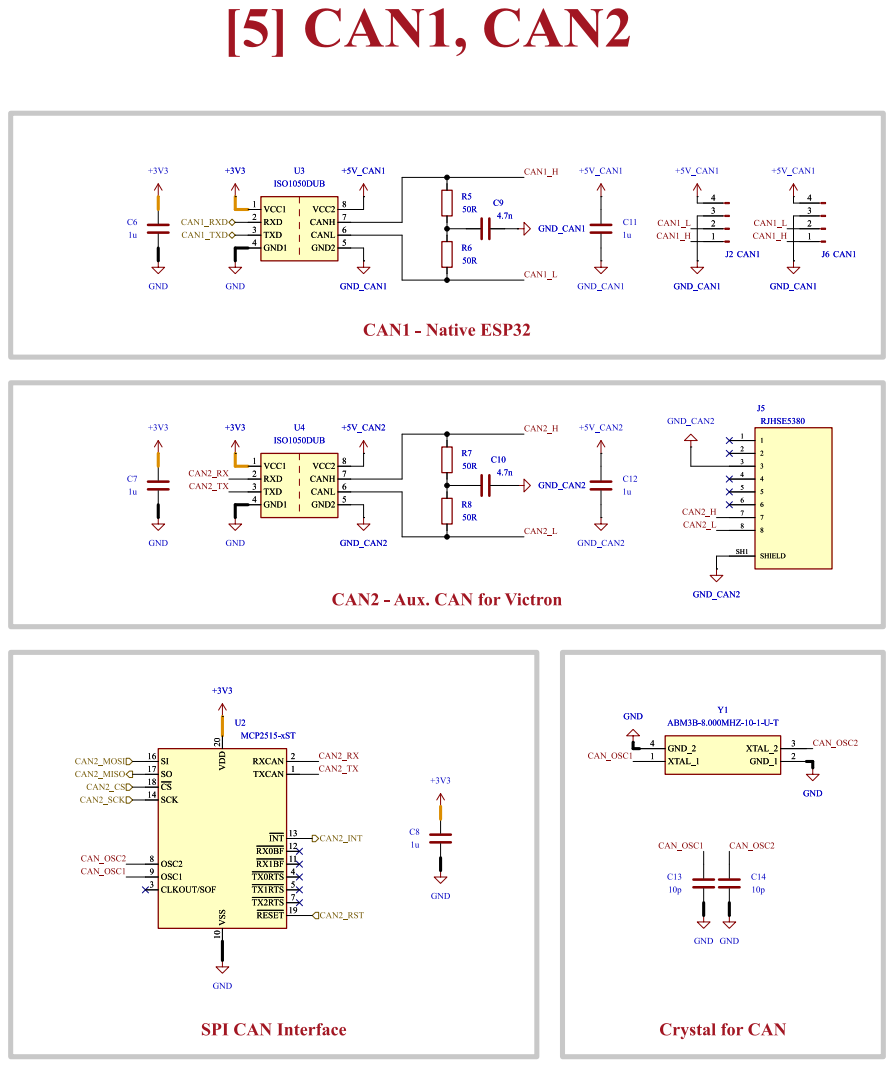
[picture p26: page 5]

CAN2 - Aux.CAN for Victron

Flexible I/O worked examples (https://jpieper.com/2022/06/30/flexible-i-o-worked-examples/) Flexible I/O source configuration References:



/ProjectArchitecture/SectionD - RTC/ Sheet Path: RTC



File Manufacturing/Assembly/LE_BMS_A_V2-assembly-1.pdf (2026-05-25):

# LE_BMS_A_V2 Assembly Document

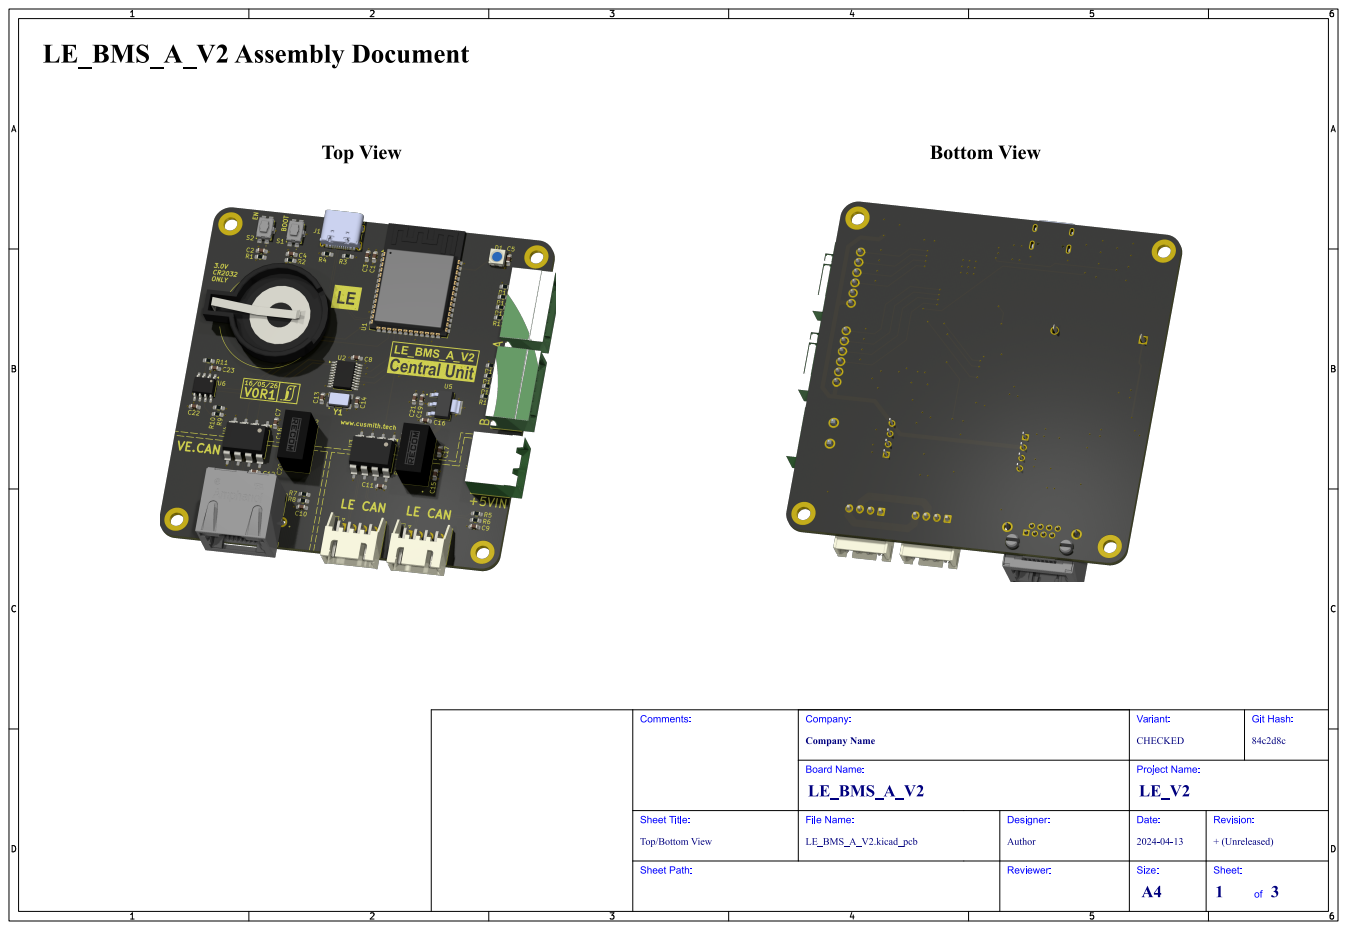
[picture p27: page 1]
Git; Hash:; Comments:; Sheet Path:; Sheet Title:; File Name:; LE_BMS_A_V2; Company Name; Company:; CHECKED; Variant:; Board Name:; LE_BMS_A_V2.kicad_pcb; Author; Designer:; Reviewer:; Project Name:; Date:; + (Unreleased); Revision:; Size:; Sheet: 1

Top/Bottom View

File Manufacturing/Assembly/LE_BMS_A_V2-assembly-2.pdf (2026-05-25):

# Top Assembly (Scale 1:1)

# LE_BMS_A_V2 Assembly Document

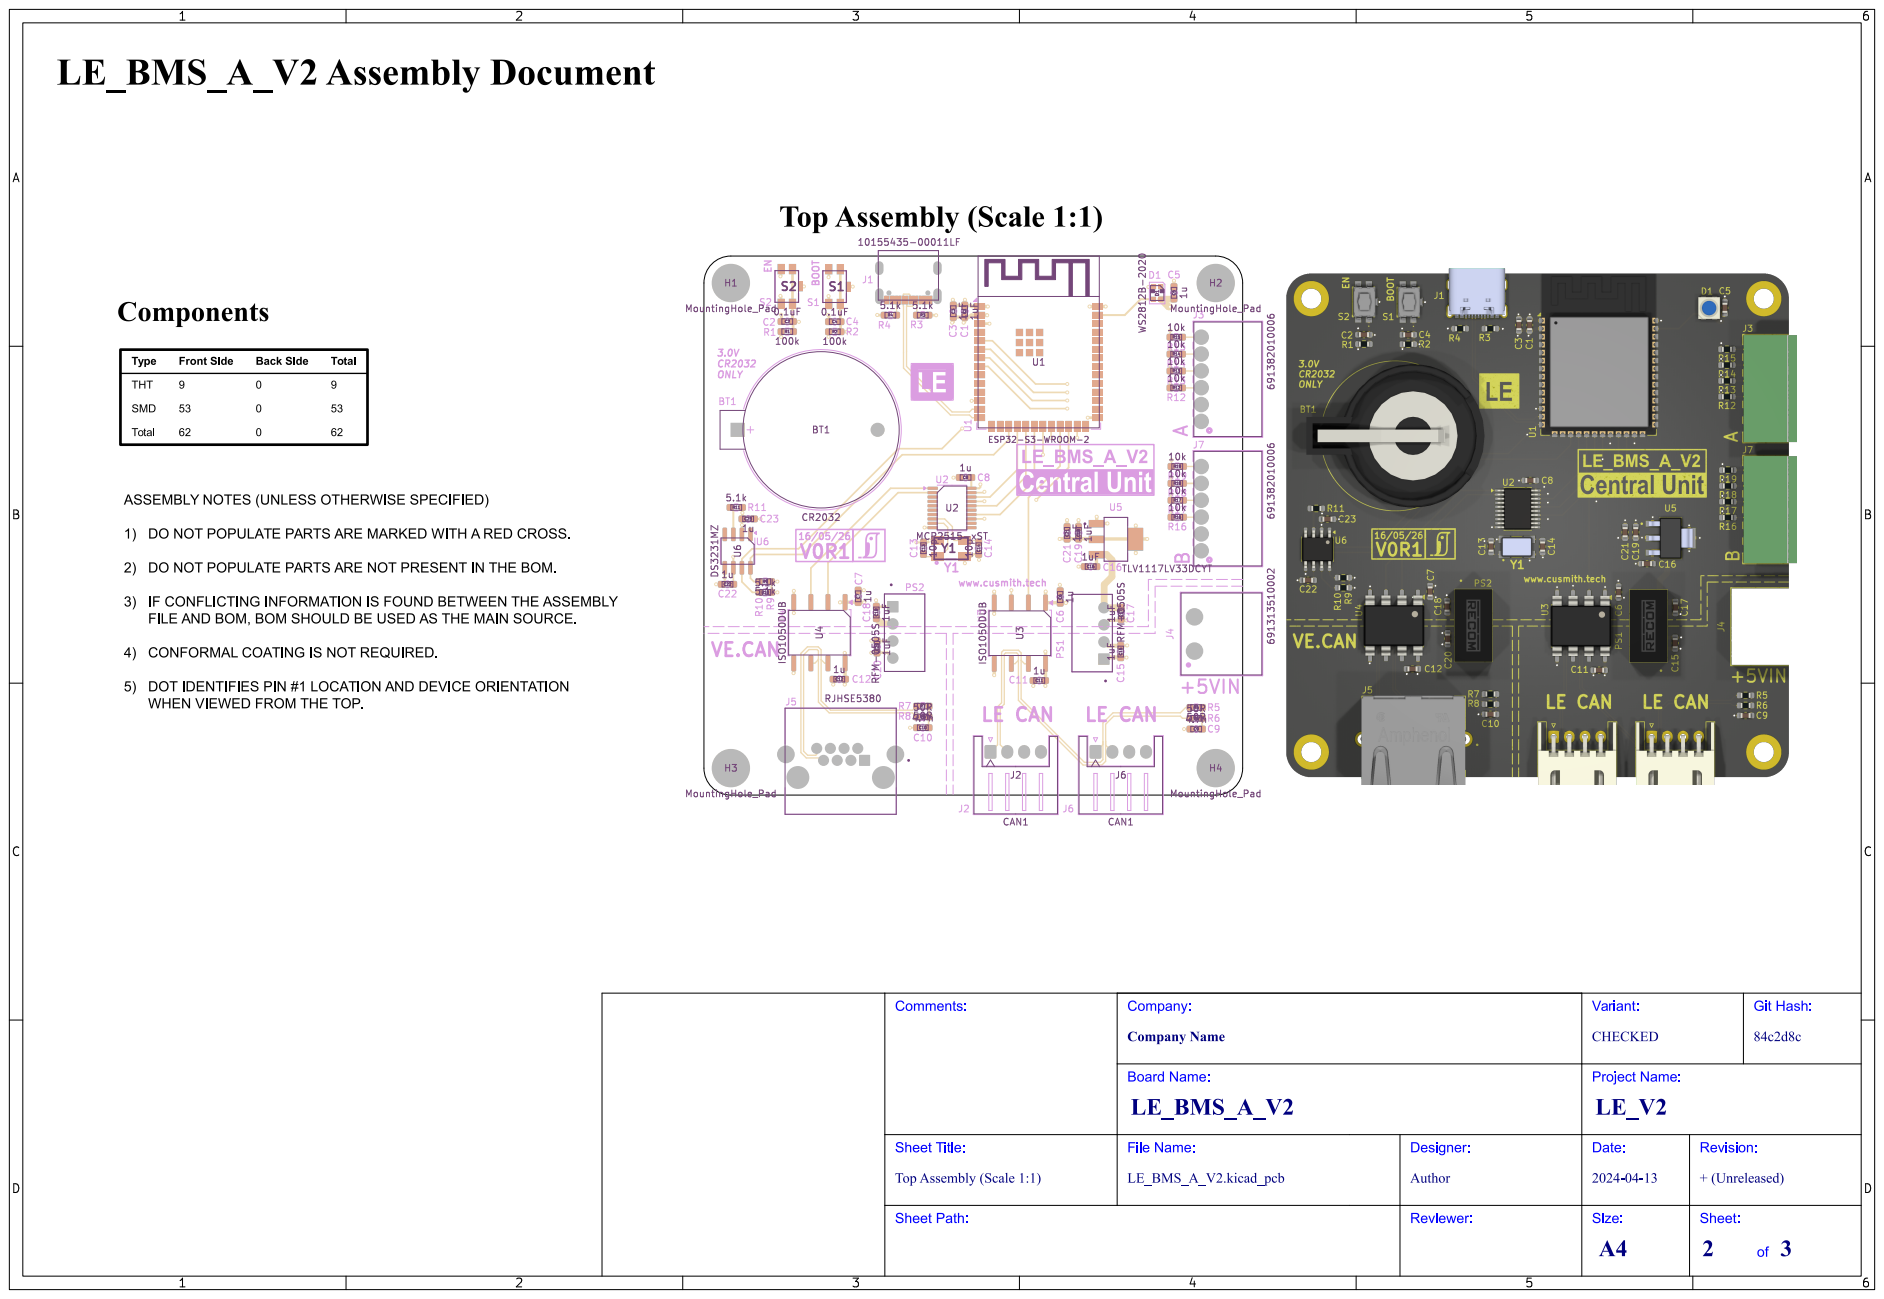
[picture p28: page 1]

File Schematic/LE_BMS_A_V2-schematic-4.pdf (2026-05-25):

6 J3 691382010006

# [4] MCU, USBandLED


IO38 31 MTCK/IO39 32 MTDO/IO40 33 MTDI/IO41 34 MTMS/IO42 35 TXD0/IO43 37 RXD0/IO44 36

/ProjectArchitecture/SectionA - Title A/ Sheet Path: MCU, USBandLED

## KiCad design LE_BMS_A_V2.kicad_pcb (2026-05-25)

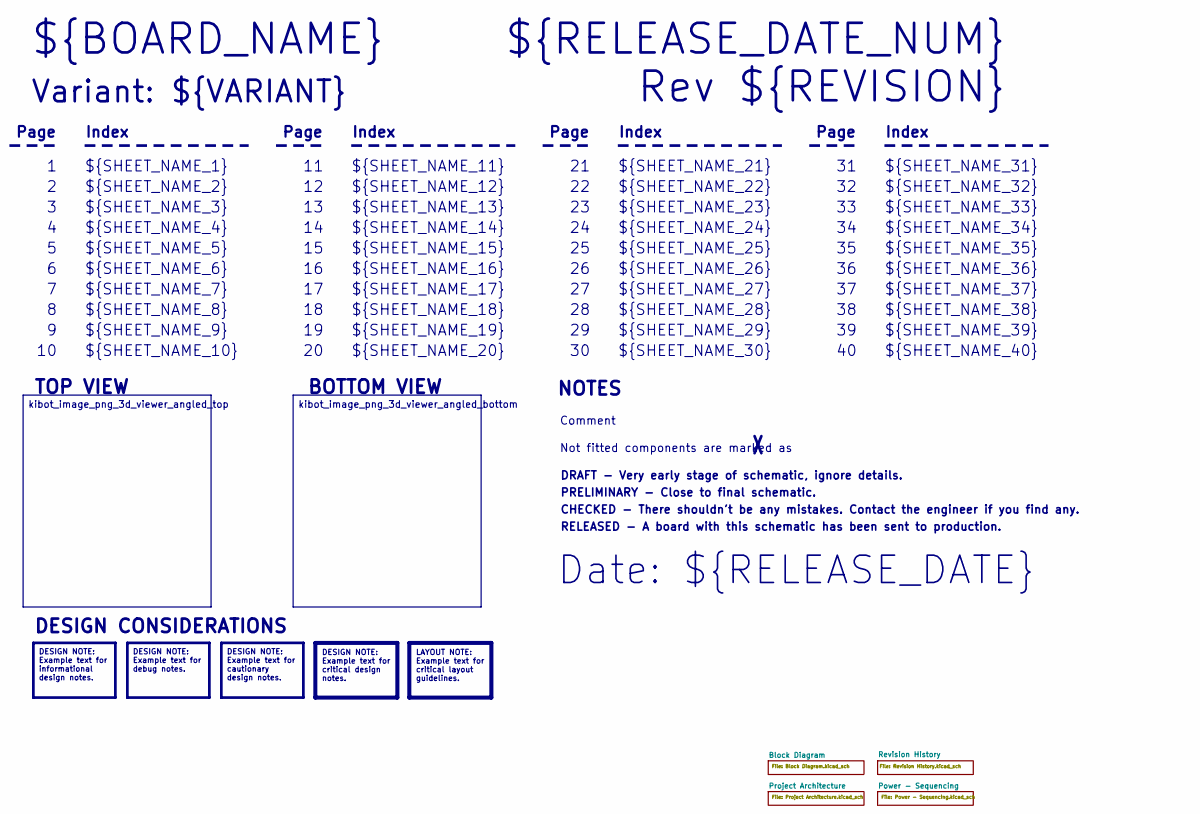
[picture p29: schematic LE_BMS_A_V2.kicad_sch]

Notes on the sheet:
Variant: ${VARIANT}
RELEASED - A board with this schematic has been sent to production.
${SHEET_NAME_24}
Index
Page
PRELIMINARY - Close to final schematic.
${SHEET_NAME_22}
DRAFT - Very early stage of schematic, ignore details.
${SHEET_NAME_12}
${SHEET_NAME_8}
${SHEET_NAME_2}
${SHEET_NAME_5}
${SHEET_NAME_20}
${SHEET_NAME_23}
${RELEASE_DATE_NUM}
${SHEET_NAME_35}
Not fitted components are marked as
${SHEET_NAME_11}
${SHEET_NAME_6}
${SHEET_NAME_37}
${SHEET_NAME_26}
${SHEET_NAME_36}
Rev ${REVISION}
${SHEET_NAME_15}
CHECKED - There shouldn't be any mistakes. Contact the engineer if you find any.
BOTTOM VIEW
${SHEET_NAME_14}
${SHEET_NAME_21}
${SHEET_NAME_17}
${SHEET_NAME_18}
Date: ${RELEASE_DATE}
${SHEET_NAME_7}
${SHEET_NAME_31}
${BOARD_NAME}
NOTES
${SHEET_NAME_40}
${SHEET_NAME_39}
${SHEET_NAME_32}
${SHEET_NAME_1}
${SHEET_NAME_9}

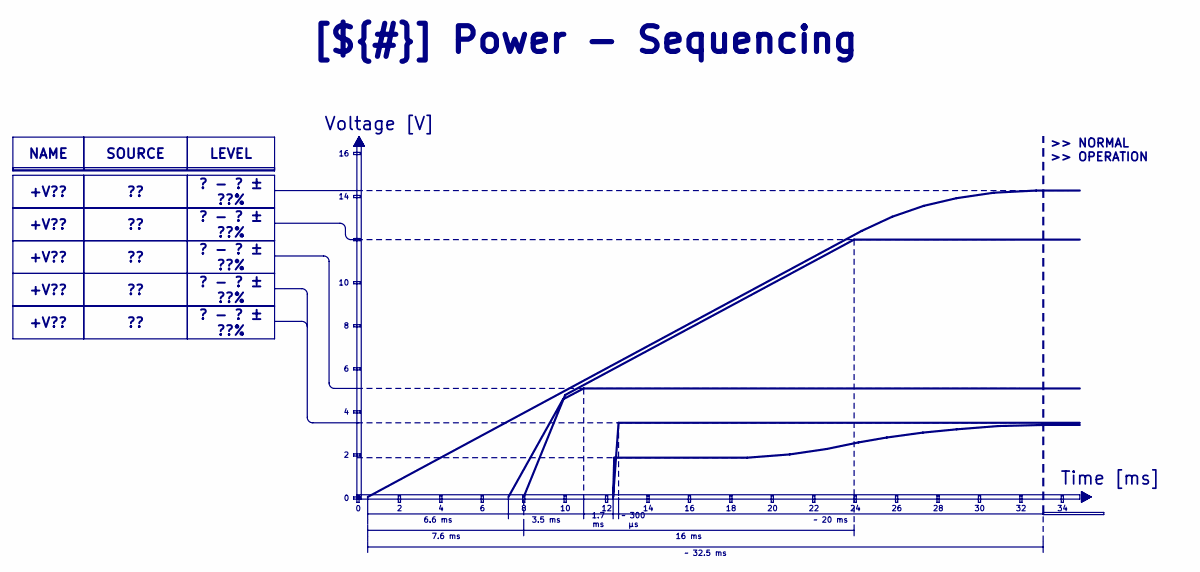
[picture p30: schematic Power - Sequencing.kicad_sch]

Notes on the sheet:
Voltage [V]
>> NORMAL >> OPERATION
Time [ms]
3.5 ms
7.6 ms
? - ? ± ??%
~ 300 μs
1.7 ms
16 ms
+V??
LEVEL
NAME
~ 20 ms
SOURCE
[${#}] ${TITLE}
6.6 ms
~ 32.5 ms


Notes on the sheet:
${RELEASE_BODY_1.1.0}
[${#}] ${TITLE}
${RELEASE_BODY_1.0.0}
${RELEASE_TITLE_1.0.2}
${RELEASE_BODY_1.0.2}
${RELEASE_BODY_1.0.1}
${RELEASE_TITLE_1.0.0}
${RELEASE_TITLE_1.0.1}
${RELEASE_TITLE_1.1.0}

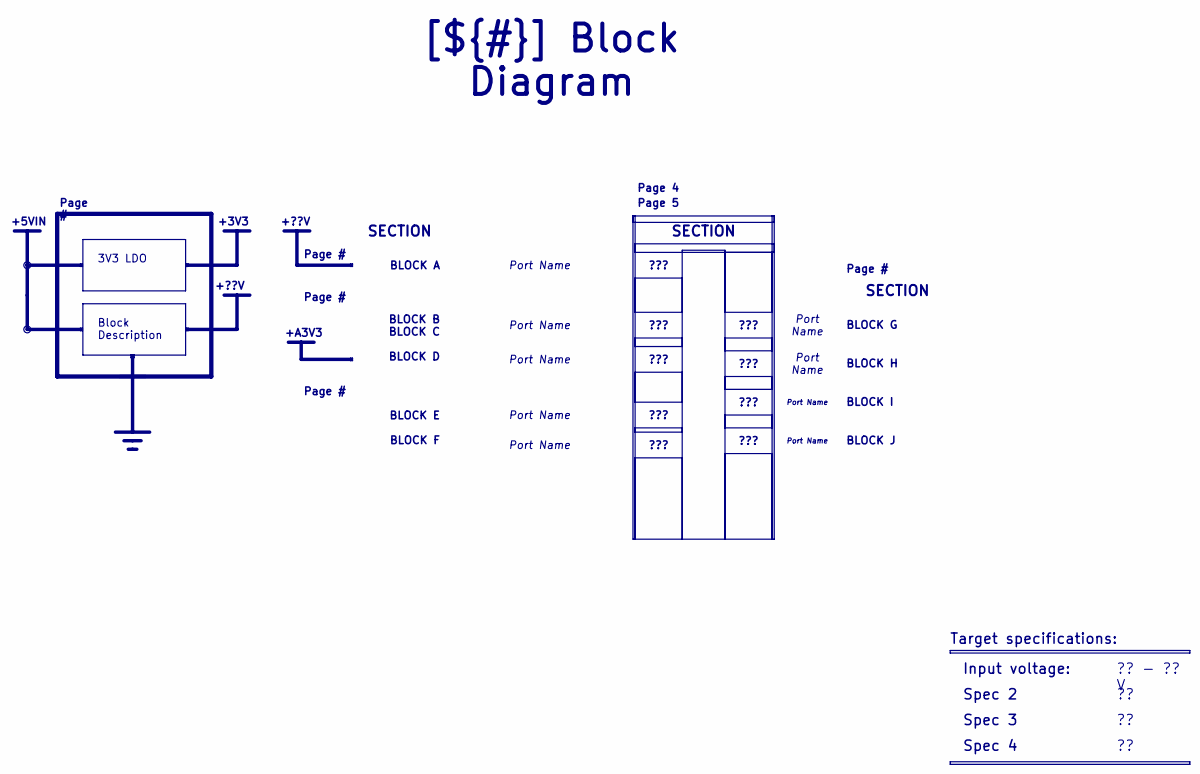
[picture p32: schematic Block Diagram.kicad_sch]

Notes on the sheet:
+5VIN
+??V
+A3V3
+3V3
SECTION
Spec 4
BLOCK H
BLOCK B BLOCK C BLOCK D
BLOCK I
?? - ?? V
3V3 LDO
???
Port Name
BLOCK G
Page #
Page 4
[${#}] ${TITLE}
Input voltage:
Target specifications:
Spec 3
Spec 2
Block Description
BLOCK A
BLOCK E BLOCK F
BLOCK J
Page 5

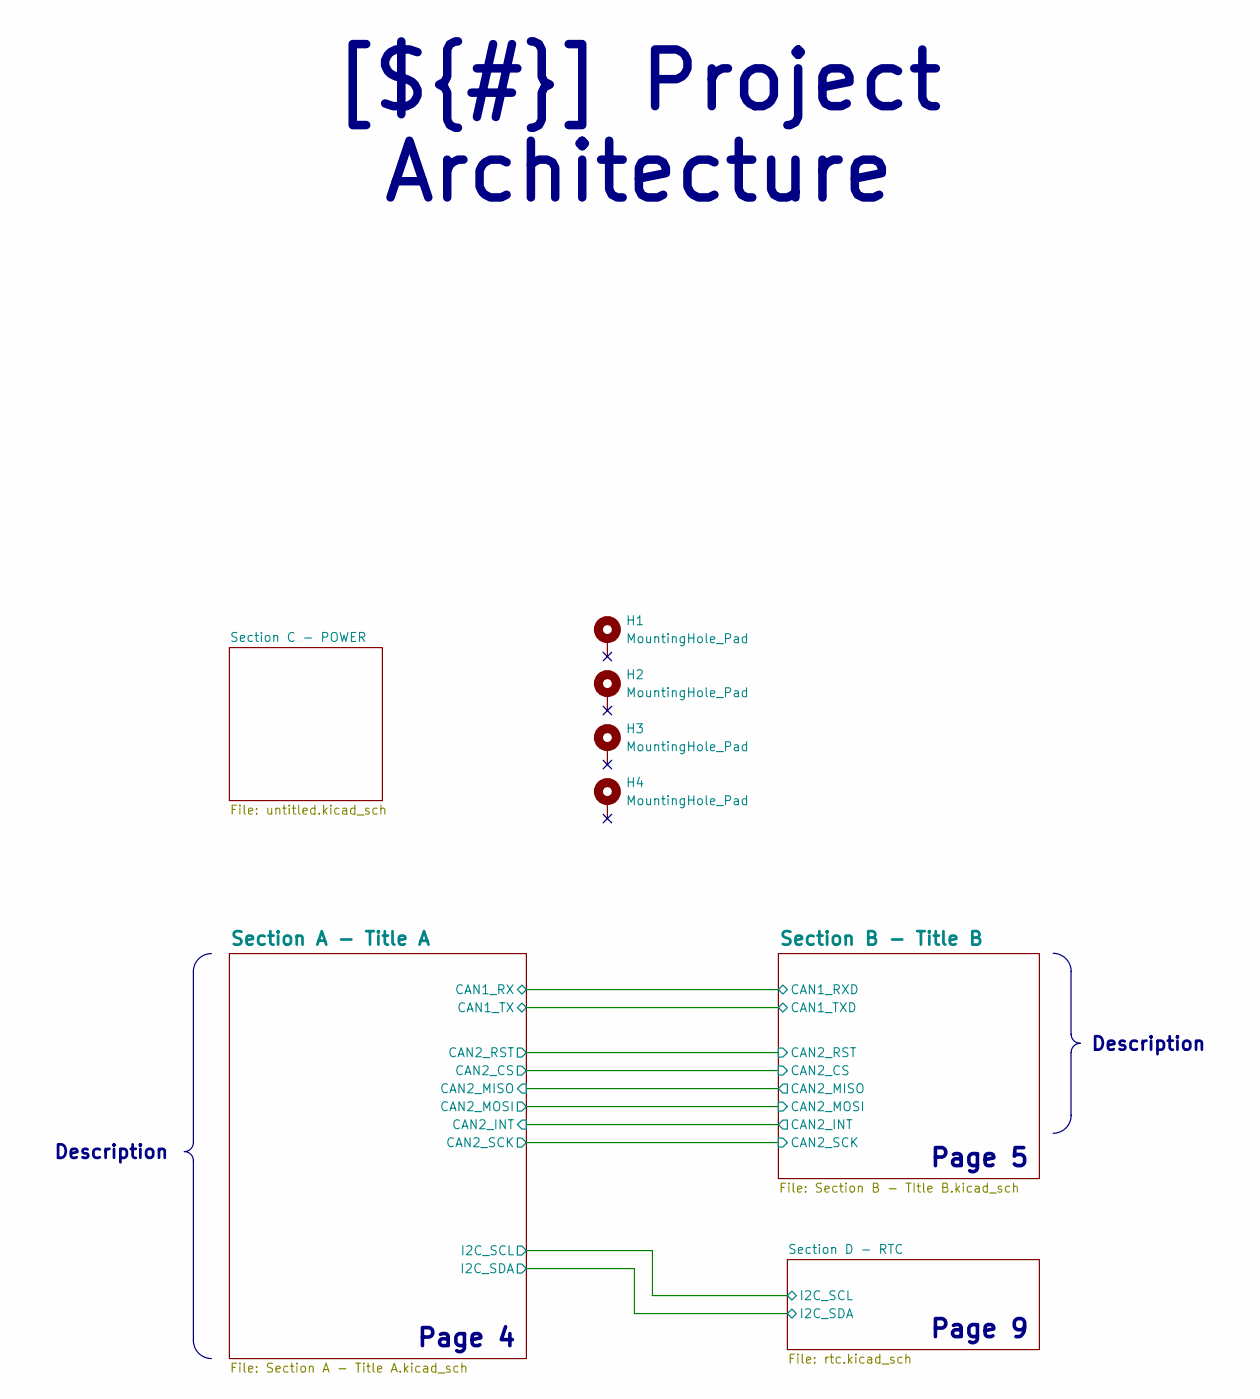
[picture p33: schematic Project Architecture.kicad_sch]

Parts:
H1, H2, H3, H4: MountingHole_Pad; MountingHole_3.2mm_M3_DIN965_Pad

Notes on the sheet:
Page 9
Page 5
Page 4
Description
[${#}] ${TITLE}

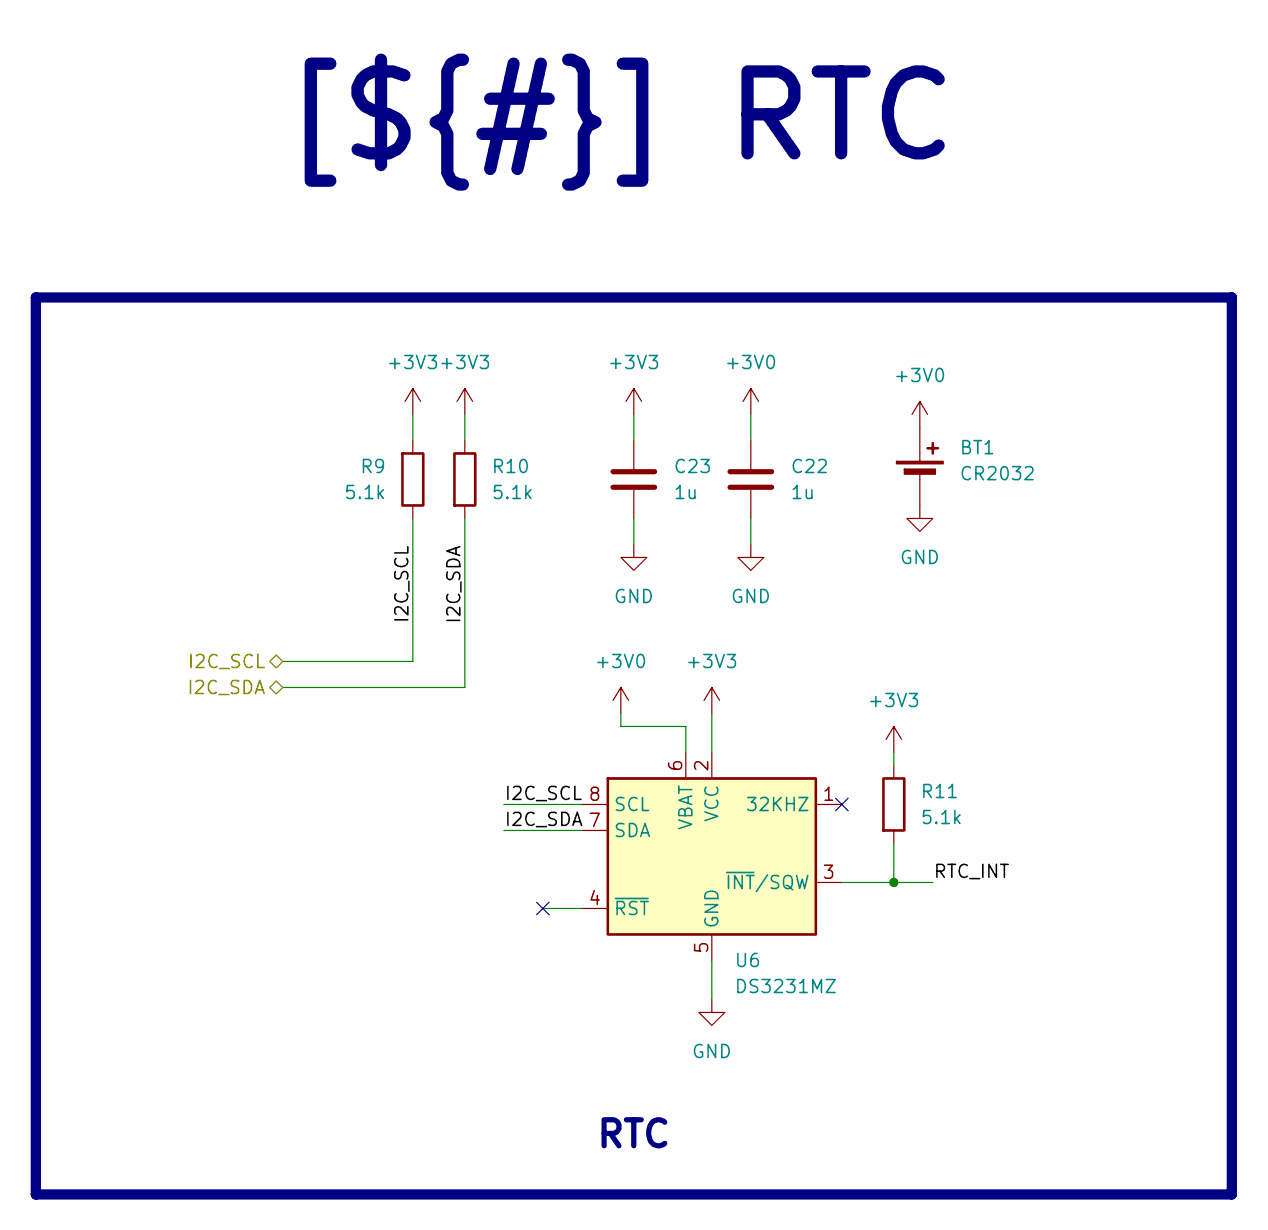
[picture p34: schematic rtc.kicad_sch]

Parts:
BT1: CR2032; BatteryHolder_MYOUNG_BS-07-A1BJ001_CR2032
C22, C23: 1u; C_0603_1608Metric_Pad1.08x0.95mm_HandSolder
R9, R10, R11: 5.1k; R_0603_1608Metric_Pad0.98x0.95mm_HandSolder
U6: DS3231MZ; SOIC-8_3.9x4.9mm_P1.27mm

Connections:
+3V0: BT1.1 (+), C22.1, U6.6 (VBAT)
+3V3: C23.1, R9.2, R10.1, R11.1, U6.2 (VCC); also elsewhere on the board
/Project Architecture/Section D - RTC/I2C_SCL: R9.1, U6.8 (SCL); also elsewhere on the board
/Project Architecture/Section D - RTC/I2C_SDA: R10.2, U6.7 (SDA); also elsewhere on the board
/Project Architecture/Section D - RTC/RTC_INT: R11.2, U6.3 (~INT/SQW)
GND: BT1.2 (-), C22.2, C23.2, U6.5 (GND); also elsewhere on the board

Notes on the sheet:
[${#}] ${TITLE}
RTC

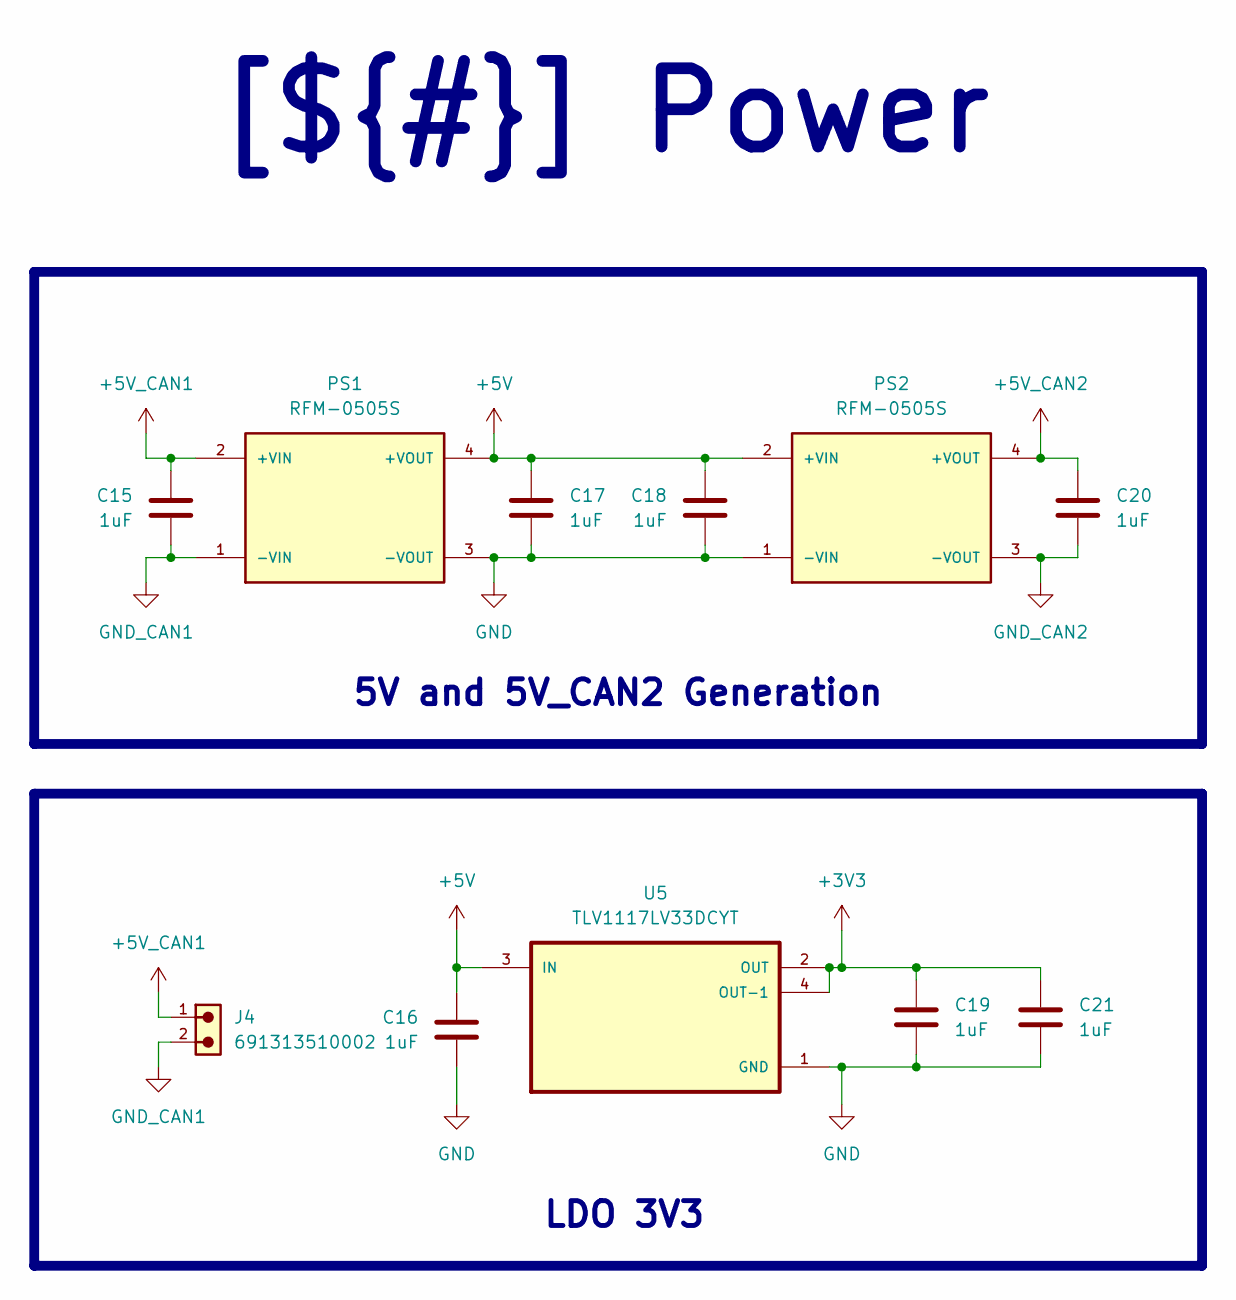
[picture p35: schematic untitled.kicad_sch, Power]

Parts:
C15, C16, C17, C18, C19, C20, C21: 1uF; C_0603_1608Metric_Pad1.08x0.95mm_HandSolder
J4: 691313510002
PS1, PS2: RFM-0505S; CONV_RFM-0505S; PARTREV 0
U5: TLV1117LV33DCYT; SOT230P700X180-4N

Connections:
+3V3: C19.1, C21.1, U5.2 (OUT), U5.4 (OUT-1); also elsewhere on the board
+5V: C16.1, C17.1, C18.1, PS1.4 (+VOUT), PS2.2 (+VIN), U5.3 (IN); also elsewhere on the board
+5V_CAN1: C15.1, J4.1, PS1.2 (+VIN); also elsewhere on the board
+5V_CAN2: C20.1, PS2.4 (+VOUT); also elsewhere on the board
GND: C16.2, C17.2, C18.2, C19.2, C21.2, PS1.3 (-VOUT), PS2.1 (-VIN), U5.1 (GND); also elsewhere on the board
GND_CAN1: C15.2, J4.2, PS1.1 (-VIN); also elsewhere on the board
GND_CAN2: C20.2, PS2.3 (-VOUT); also elsewhere on the board

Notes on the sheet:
[${#}] ${TITLE}
5V and 5V_CAN2 Generation
LDO 3V3

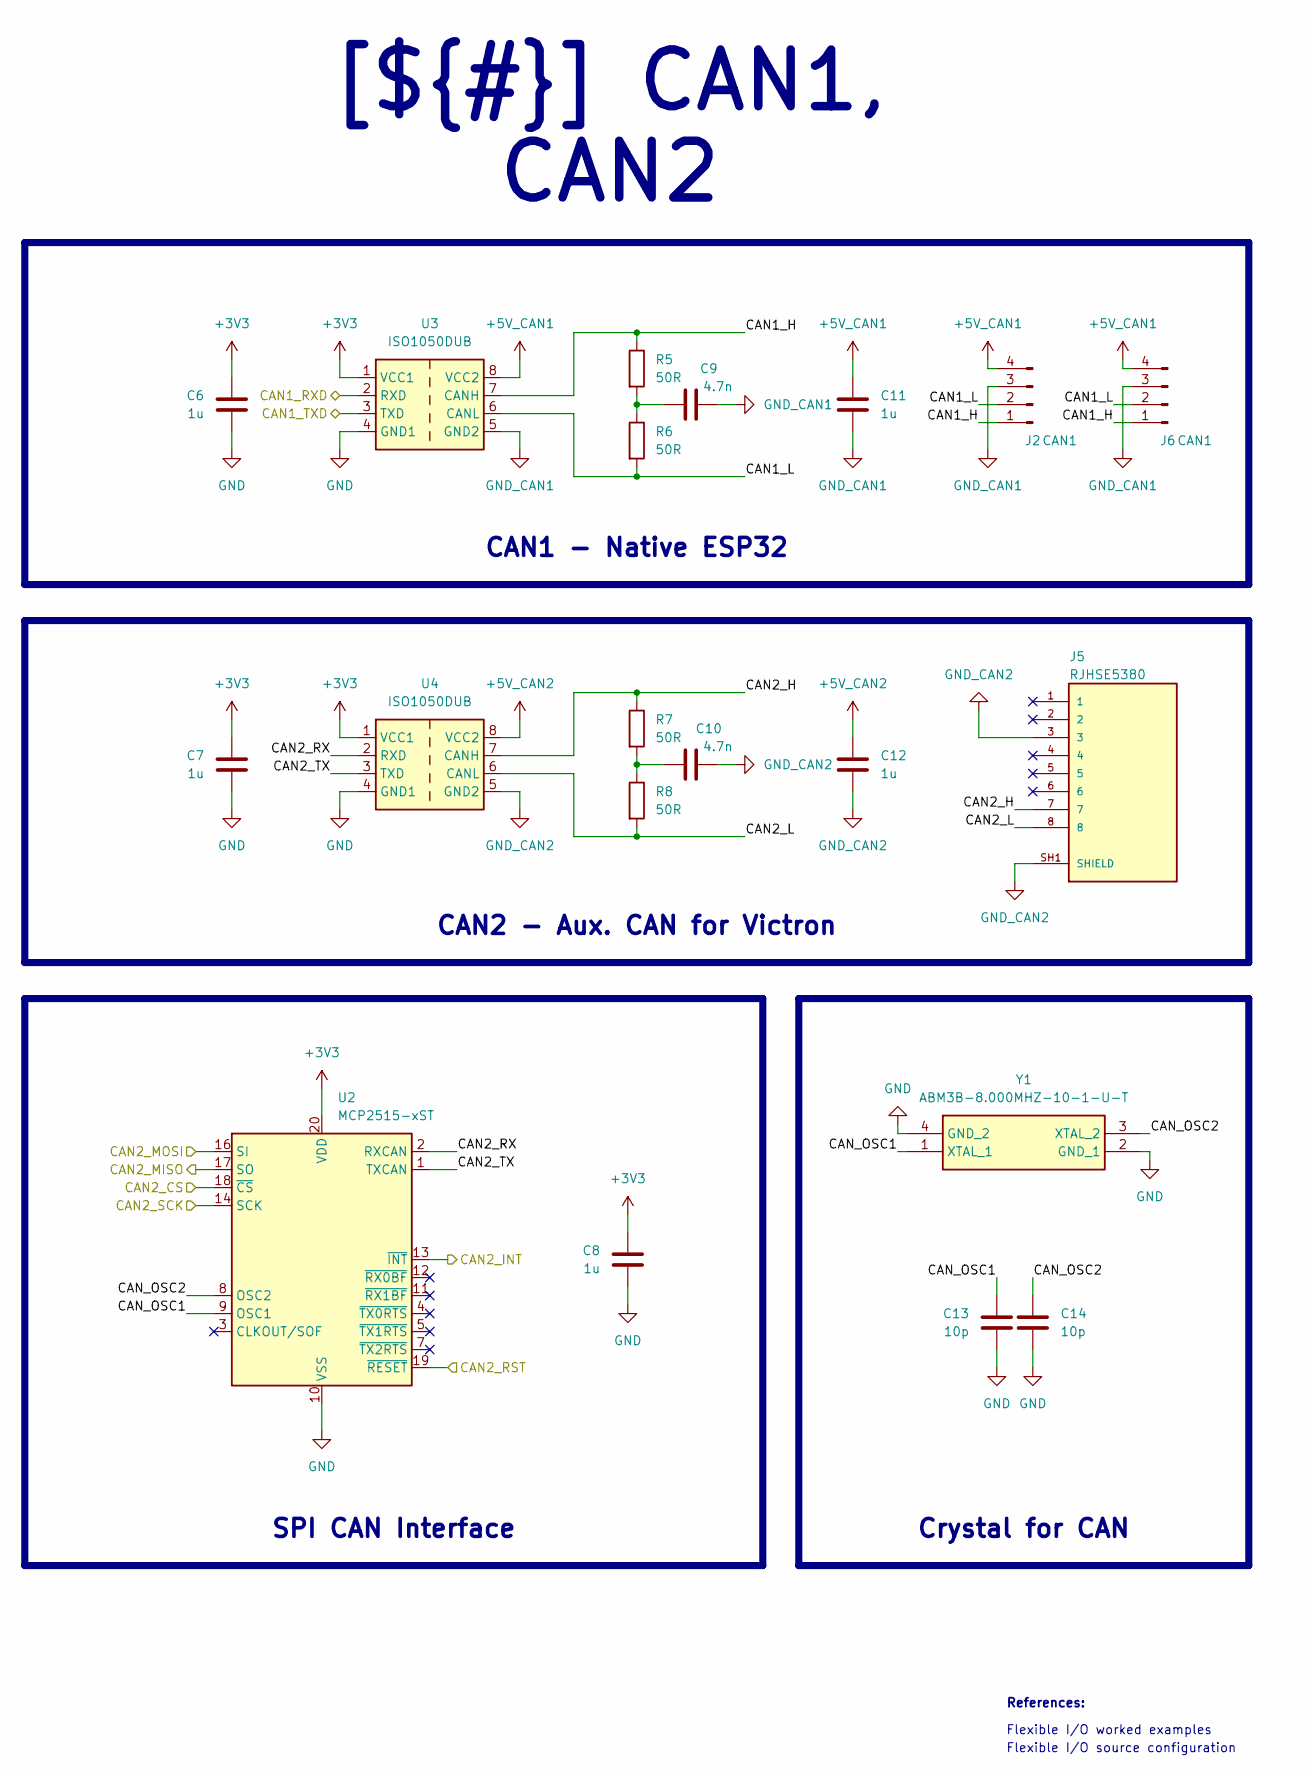
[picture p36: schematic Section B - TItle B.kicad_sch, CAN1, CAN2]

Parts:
C6, C7, C8, C11, C12: 1u; C_0603_1608Metric_Pad1.08x0.95mm_HandSolder
C9, C10: 4.7n; C_0603_1608Metric_Pad1.08x0.95mm_HandSolder
C13, C14: 10p; C_0603_1608Metric_Pad1.08x0.95mm_HandSolder
J2, J6: CAN1; JST_XH_S4B-XH-A_1x04_P2.50mm_Horizontal
J5: RJHSE5380; AMPHENOL_RJHSE5380; PARTREV B
R5, R6, R7, R8: 50R; R_0603_1608Metric_Pad0.98x0.95mm_HandSolder
U2: MCP2515-xST; TSSOP-20_4.4x6.5mm_P0.65mm
U3, U4: ISO1050DUB; SOP-8_6.62x9.15mm_P2.54mm
Y1: ABM3B-8.000MHZ-10-1-U-T; ABM3B; Mouser Part Number 815-ABM3B8MHZ101UT

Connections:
+3V3: C6.1, C7.1, C8.1, U2.20 (VDD), U3.1 (VCC1), U4.1 (VCC1); also elsewhere on the board
+5V_CAN1: C11.1, J2.4, J6.4, U3.8 (VCC2); also elsewhere on the board
+5V_CAN2: C12.1, U4.8 (VCC2); also elsewhere on the board
/Project Architecture/Section A - Title A/CAN1_RX: U3.2 (RXD); also elsewhere on the board
/Project Architecture/Section A - Title A/CAN1_TX: U3.3 (TXD); also elsewhere on the board
/Project Architecture/Section A - Title A/CAN2_CS: U2.18 (~CS); also elsewhere on the board
/Project Architecture/Section A - Title A/CAN2_INT: U2.13 (~INT); also elsewhere on the board
/Project Architecture/Section A - Title A/CAN2_MISO: U2.17 (SO); also elsewhere on the board
/Project Architecture/Section A - Title A/CAN2_MOSI: U2.16 (SI); also elsewhere on the board
/Project Architecture/Section A - Title A/CAN2_RST: U2.19 (~RESET); also elsewhere on the board
/Project Architecture/Section A - Title A/CAN2_SCK: U2.14 (SCK); also elsewhere on the board
/Project Architecture/Section B - Title B/CAN1_H: J2.1, J6.1, R5.1, U3.7 (CANH)
/Project Architecture/Section B - Title B/CAN1_L: J2.2, J6.2, R6.2, U3.6 (CANL)
/Project Architecture/Section B - Title B/CAN2_H: J5.7, R7.1, U4.7 (CANH)
/Project Architecture/Section B - Title B/CAN2_L: J5.8, R8.2, U4.6 (CANL)
/Project Architecture/Section B - Title B/CAN2_RX: U2.2 (RXCAN), U4.2 (RXD)
/Project Architecture/Section B - Title B/CAN2_TX: U2.1 (TXCAN), U4.3 (TXD)
/Project Architecture/Section B - Title B/CAN_OSC1: C13.1, U2.9 (OSC1), Y1.1 (XTAL_1)
/Project Architecture/Section B - Title B/CAN_OSC2: C14.1, U2.8 (OSC2), Y1.3 (XTAL_2)
GND: C6.2, C7.2, C8.2, C13.2, C14.2, U2.10 (VSS), U3.4 (GND1), U4.4 (GND1), Y1.2 (GND_1), Y1.4 (GND_2); also elsewhere on the board
GND_CAN1: C9.2, C11.2, J2.3, J6.3, U3.5 (GND2); also elsewhere on the board
GND_CAN2: C10.2, C12.2, J5.3, J5.SH1 (SHIELD), J5.SH2 (SHIELD), U4.5 (GND2); also elsewhere on the board
unnamed: C9.1, R5.2, R6.1
unnamed: C10.1, R7.2, R8.1

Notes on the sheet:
Flexible I/O worked examples
References:
Flexible I/O source configuration
[${#}] ${TITLE}
CAN1 - Native ESP32
CAN2 - Aux. CAN for Victron
Crystal for CAN
SPI CAN Interface

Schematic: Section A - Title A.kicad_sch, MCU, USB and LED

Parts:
C1, C3: 1uF; C_0603_1608Metric_Pad1.08x0.95mm_HandSolder
C2, C4: 0.1uF; C_0603_1608Metric_Pad1.08x0.95mm_HandSolder
C5: 1u; C_0603_1608Metric_Pad1.08x0.95mm_HandSolder
D1: WS2812B-2020; LED_WS2812B-2020_PLCC4_2.0x2.0mm
J1: 10155435-00011LF; AMPHENOL_10155435-00011LF; PARTREV C
J3, J7: 691382010006
R1, R2: 100k; R_0603_1608Metric_Pad0.98x0.95mm_HandSolder
R3, R4: 5.1k; R_0603_1608Metric_Pad0.98x0.95mm_HandSolder
R12, R13, R14, R15, R16, R17, R18, R19: 10k; R_0603_1608Metric_Pad0.98x0.95mm_HandSolder
S1, S2: EVQ-P2P02W; EVQP2P02W; Mouser Part Number 667-EVQ-P2P02W
U1: ESP32-S3-WROOM-2

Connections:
+3V3: C1.1, C3.1, R1.1, R2.1, U1.2 (3V3); also elsewhere on the board
+5V: C5.1, D1.4 (VDD), J3.1, J7.1; also elsewhere on the board
/Project Architecture/Section A - Title A/CAN1_RX: U1.23 (IO21); also elsewhere on the board
/Project Architecture/Section A - Title A/CAN1_TX: U1.24 (IO47); also elsewhere on the board
/Project Architecture/Section A - Title A/CAN2_CS: U1.18 (IO10); also elsewhere on the board
/Project Architecture/Section A - Title A/CAN2_INT: U1.25 (IO48); also elsewhere on the board
/Project Architecture/Section A - Title A/CAN2_MISO: U1.21 (IO13); also elsewhere on the board
/Project Architecture/Section A - Title A/CAN2_MOSI: U1.19 (IO11); also elsewhere on the board
/Project Architecture/Section A - Title A/CAN2_RST: U1.22 (IO14); also elsewhere on the board
/Project Architecture/Section A - Title A/CAN2_SCK: U1.20 (IO12); also elsewhere on the board
/Project Architecture/Section A - Title A/ESP32_BOOT: C4.1, R2.2, S1.1 (NO_1), S1.3 (NO_2), U1.27 (IO0)
/Project Architecture/Section A - Title A/ESP32_EN: C2.1, R1.2, S2.1 (NO_1), S2.3 (NO_2), U1.3 (EN)
/Project Architecture/Section A - Title A/ESP32_USB_D+: J1.A6 (DP1), J1.B6 (DP2), U1.14 (USB_D+/IO20)
/Project Architecture/Section A - Title A/ESP32_USB_D-: J1.A7 (DN1), J1.B7 (DN2), U1.13 (USB_D-/IO19)
/Project Architecture/Section A - Title A/GPIO_A1: J3.3, R12.1, U1.35 (MTMS/IO42)
/Project Architecture/Section A - Title A/GPIO_A2: J3.4, R13.1, U1.36 (RXD0/IO44)
/Project Architecture/Section A - Title A/GPIO_A3: J3.5, R14.1, U1.37 (TXD0/IO43)
/Project Architecture/Section A - Title A/GPIO_A4: J3.6, R15.1, U1.38 (IO2)
/Project Architecture/Section A - Title A/GPIO_B1: J7.3, R16.1, U1.8 (IO15)
/Project Architecture/Section A - Title A/GPIO_B2: J7.4, R17.1, U1.7 (IO7)
/Project Architecture/Section A - Title A/GPIO_B3: J7.5, R18.1, U1.6 (IO6)
/Project Architecture/Section A - Title A/GPIO_B4: J7.6, R19.1, U1.5 (IO5)
/Project Architecture/Section A - Title A/LED_DOUT: D1.3 (DIN), U1.39 (IO1)
/Project Architecture/Section A - Title A/USB_CC1: J1.A5 (CC1), R3.2
/Project Architecture/Section A - Title A/USB_CC2: J1.B5 (CC2), R4.1
/Project Architecture/Section D - RTC/I2C_SCL: U1.17 (IO9); also elsewhere on the board
/Project Architecture/Section D - RTC/I2C_SDA: U1.12 (IO8); also elsewhere on the board
GND: C1.2, C2.2, C3.2, C4.2, C5.2, D1.2 (VSS), J1.A1_B12 (GND), J1.B1_A12 (GND), J1.SH1 (SHIELD), J1.SH2 (SHIELD), J1.SH3 (SHIELD), J1.SH4 (SHIELD), J3.2, J7.2, R3.1, R4.2, R12.2, R13.2, R14.2, R15.2, R16.2, R17.2, R18.2, R19.2, S1.2 (COM_1), S1.4 (COM_2), S1.G1 (GND), S2.2 (COM_1), S2.4 (COM_2), S2.G1 (GND), U1.1 (GND), U1.40 (GND), U1.41 (GND); also elsewhere on the board

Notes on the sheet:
J. Pieper ADC investigation
STM32G474 Datasheet p.81
AN5346
USB-C
Reset buttons
Neopixel LED
LAYOUT NOTE: Differential Pair
Terminal block
[${#}] ${TITLE}
MCU

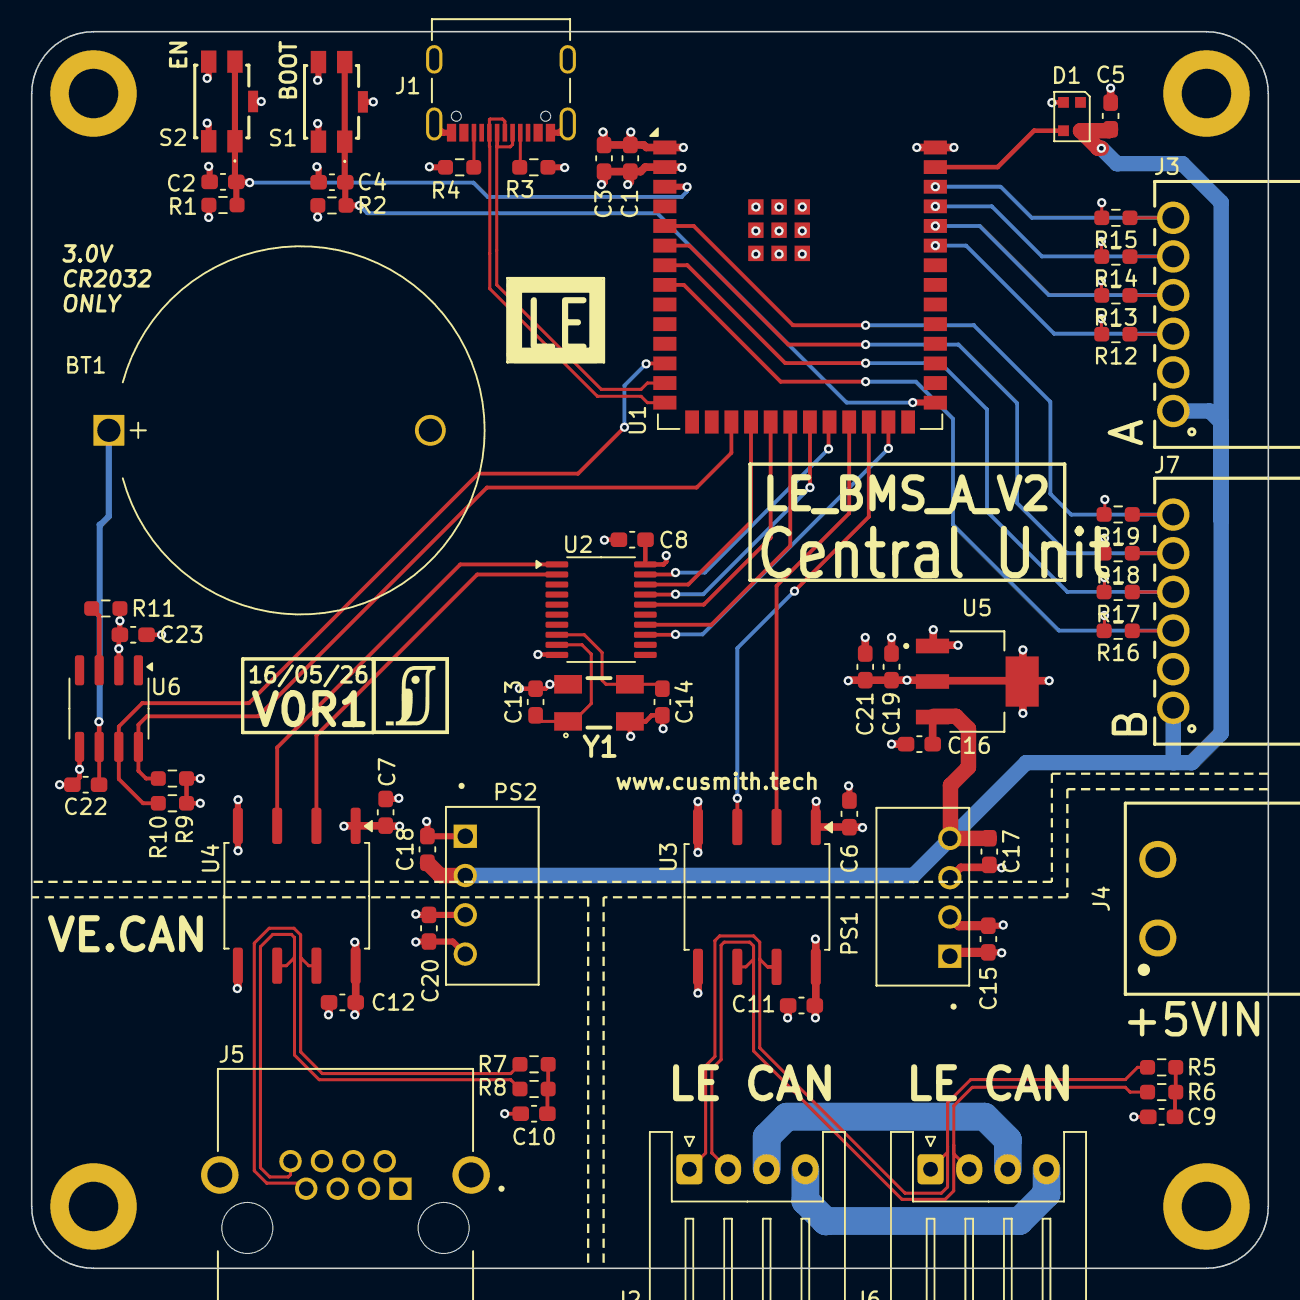
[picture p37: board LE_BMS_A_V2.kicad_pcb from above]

Board: 4 copper layers, 80.0 x 80.0 mm, 66 parts (0 on the bottom side), 44 nets.

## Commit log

2026-05-16 Initial commit: Moved over previous design and added isolation to CAN bus.
    [10155435-00011LF.step, 691313510002.step, ABM3B-8.000MHZ-10-1-U-T.stp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]
2026-05-16 Update Outputs
    [LE_BMS_A_V2-(L1-L4)_NPTH_drill_table.csv, LE_BMS_A_V2-(L1-L4)_drill_table.csv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]
2026-05-16 Moved the PCB a bit.
    [LE_BMS_A_V2.kicad_pcb]
2026-05-18 Finished most routing, final checks to be done
    [691382010006.step, LE_BMS_A_V2.kicad_pcb, Section A - Title A.kicad_sch]
2026-05-25 Final Changes, Updated to Checked
    [LE_BMS_A_V2.kicad_pcb, Project Architecture.kicad_sch, Section A - Title A.kicad_sch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]
2026-05-25 Retry with rules DRC ERC passing
    [LE_BMS_A_V2.kicad_pcb, Project Architecture.kicad_sch, Section A - Title A.kicad_sch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]
2026-05-25 Increased Via Sizes to 0.3/0.6
    [LE_BMS_A_V2.kicad_pcb]
2026-05-25 Added pulldowns on GPIOs
    [LE_BMS_A_V2.kicad_pcb, Section A - Title A.kicad_sch]
2026-05-25 Final Commit on this Version
    [LE_BMS_A_V2-CPL.csv]
2026-05-25 Added JLCPCB BoM for Assembly
    [BOM_LE_BMS_A_V2-JLCPCB Assembly Order-JLCPCB Assembly Order.xls]
